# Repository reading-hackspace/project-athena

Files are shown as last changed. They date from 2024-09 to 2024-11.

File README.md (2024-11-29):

# Project Athena

A simple project to build and learn electronics and embedded design at rLab

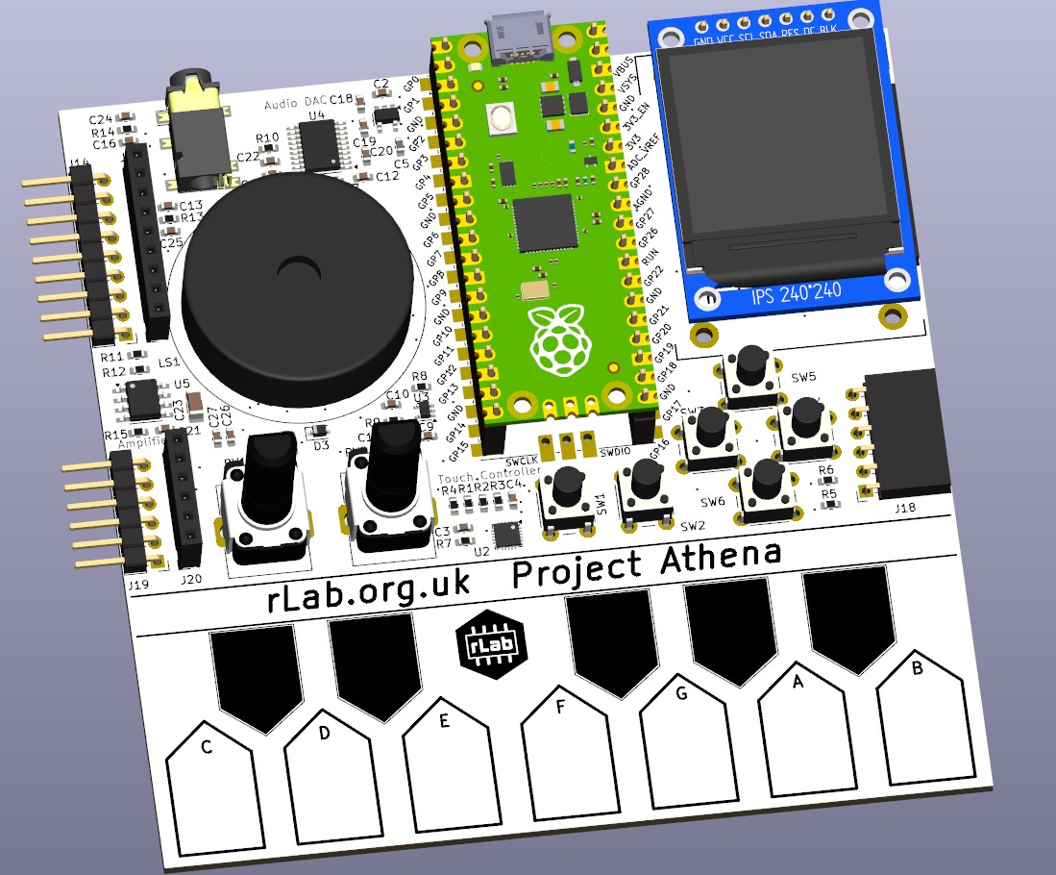
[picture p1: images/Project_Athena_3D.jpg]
Project Athena 3D


## Objectives:
<ul>
<li>Develop individual and shared electronic design skills</li>
<li>Learn PCB design and build techniques with Kicad and external PCB manufacturers</li>
<li>Improve surface mount and through hole soldering skills</li>
<li>Familiarise members with rLab electronics tools, equipment, and knowledge</li>
<li>Make a fun device</li>
</ul>

## Design Specification
Derived from the previous 555 Synth Punk construction project
<ul>
<li>design should be Microprocessor based rather than 555</li>
<li>It should have a keyboard. This could be buttons, stylophone, touch sensor, or other. Probably single octave.</li>
<li>Cost components and board under £10</li>
<li>Improved Audio output using proper amplifier IC and board mounted speaker, possibly I2S codec</li>
<li>A couple of knobs and buttons to change sound settings</li>
<li>USB powered</li>
<li>Audio output jack</li>
<li>Mixture of surface mount and through hole components</li>
<li>LCD display integral</li> 
<li>Expansion connector to add new personalised features</li>v
<li>C++ or Python programming.</li>
</ul>

## Design Approach
The design is built of modules which can be independently sourced, designed and prototyped before integration into a complete design.

## Proposed Modules
The following modules are proposed to be in the design, being available and at reasonable cost:

### Raspberry Pi Pico Processor Module
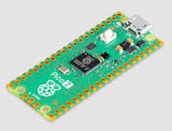
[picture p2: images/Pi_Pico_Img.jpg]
Pi Pico Image


The Raspberry Pi Pico module is based on the RP2040 microprocessor. The module includes flash memory, power supply, crystal clock and a USB interface. It is an easy way to to integrate this processor without detail PCB layout and at attractive cost.
The Pi Pico Module have different variants which are pin compatible. They offer different USB Connectors(Micro-B, USB-C), Wireless and bluetooth integrated, and a higher performance version in the RP2350.
[Pi Pico Data sheet](https://datasheets.raspberrypi.com/pico/pico-datasheet.pdf)

The RP2040 is an ARM Cortex M0+ 32 bit processor which operates at 133MHz and includes a wide range of integrated peripherals.
[RP2040 Data sheet](https://datasheets.raspberrypi.com/rp2040/rp2040-datasheet.pdf)

High quality software support for the RP2040 and Pi Pico Modules is available in C/C++ ([C SDK](https://www.raspberrypi.com/documentation/microcontrollers/c_sdk.html), and [Arduino Pi Pico](https://www.tomshardware.com/how-to/program-raspberry-pi-pico-with-arduino-ide)), and Python([Micropython](https://www.raspberrypi.com/documentation/microcontrollers/micropython.html), and [CircuitPython](https://circuitpython.org/board/raspberry_pi_pico/))

### Capacitive touch Music Keyboard
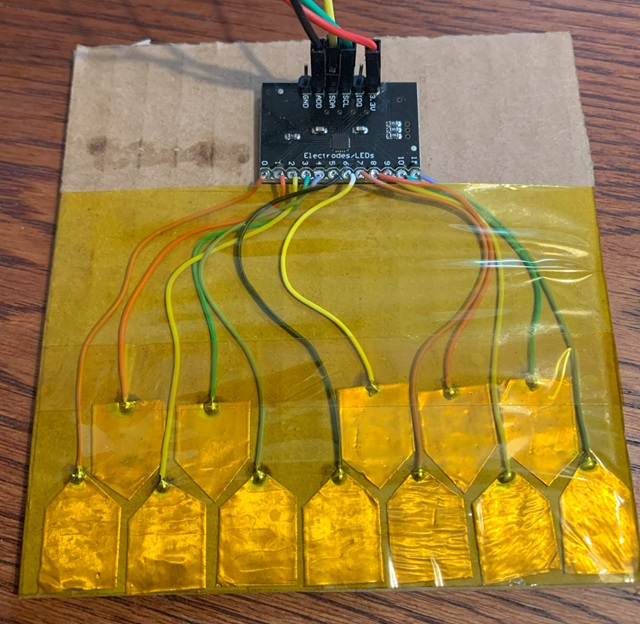
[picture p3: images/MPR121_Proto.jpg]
MPR121 Proto

A number of different keyboard switch types were considered including push butttons, stylophone type stylus and capacitive touch. The later was chosen for simplicity and the capability to play chords with multiple notes simultaneously.

A few different alternatives for the capacitive touch keyboard layout and interface were tested. The keyboard was prototyped with copper tape covered in kapton tape to simulate the PCB pads and solder mask in the final PCB. The Pi Pico does support direct connection of GPIO pins to interface capacitive touch switches using the CircuitPython [touchio library](https://docs.circuitpython.org/en/latest/shared-bindings/touchio/index.html), However it uses a lot of GPIO pins for a 12 key keyboard. It was decided to us a specialised Capacitive touch chip with and I2C interface [MPR121](https://www.nxp.com/docs/en/data-sheet/MPR121.pdf). This chip is very small and will present a good challenge in construction, however it is available already mounted on low cost modules for prototyping. The chip supports up to 4 different I2C addresses allowing additional octave to be added.

### PWM Audio Output
The Pi Pico supports PWM output to a GPIO pin for audio tone output. The resulting output is rather noisy as described in section 3.4.1 of the  [RP2040 hardware interface manual](https://datasheets.raspberrypi.com/rp2040/hardware-design-with-rp2040.pdf). It was chosen to implement the low noise 3.3V audio supply, the buffer, and the filter circuit.

### I2S Audio Codec
In addition to the PWM a I2S audio DAC is included for higher quality stereo output. The [PCM5102 DAC](https://www.ti.com/lit/ds/symlink/pcm5102.pdf) analog part is also powered from the low noise 3.3V supply

### Audio Amplifier and Loudspeaker
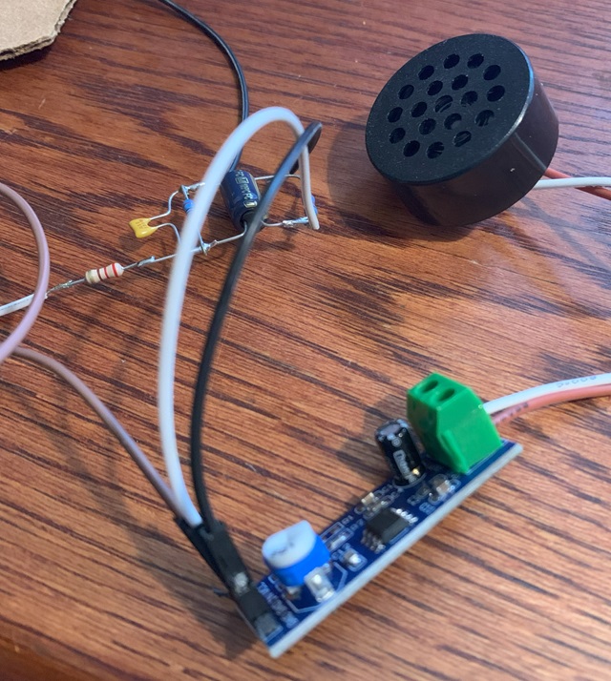
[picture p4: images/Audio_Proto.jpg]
Audio proto


Low cost audio power amplifiers with 1W output power baaed on the LM386 are available. [LM386 module](https://www.switchelectronics.co.uk/products/lm386-audio-amplifier-board-200-gain-amplifier-module-power)

The LM386 IC can operate with few external components with a gain of 20 which is suitable for our application.[LM386 Data sheet](https://www.ti.com/lit/ds/symlink/lm386.pdf)

The loudspeaker is proposed to be board mounted.[30mm Loudspeaker](https://proto-pic.co.uk/product/speaker-30mm-dia-8-ohm-pcb-mounted)

Audio Output to an external amplifier is provided via a 3.5mm stereo jack.

### 1.3 inch IPS Colour LCD Display
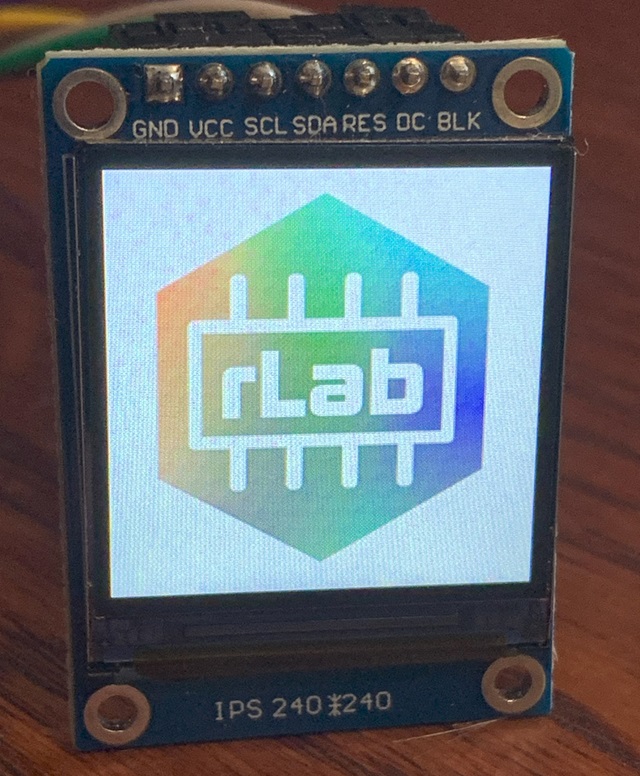
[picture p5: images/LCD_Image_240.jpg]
LCD Image


A colour LCD display was chosen for the device. Limited space allows for a [240 by 240 pixel 1.3 inch IPS display](https://www.smart-prototyping.com/1_3-inch-TFT-IPS-Display-Module-ST7789-SPI-240-240).
The module is based on the ST7789 display IC and is supported by both Micropython and CircuitPython grahics libraries.

### Buttons and Potentiometers.

To interact with the device and display, two potentiometers and six push buttons are included.

### General Purpose Inputs and Outputs.

The board provides spare GPIO connections and power supplies on 2.54mm female headers for external experimental devices. The I2c Bus is also brought out to a connectors to daisy chain octaves or add other I2C devices. The connectors can be male or female and mounted vertically or horizontally on the board

##   Estimated Costs
Derived from Kicad BOM. All including VAT and shipping.
<ul>
<li> PCB, 2 layer 100mm * 100mm JLCPCB      £0.75</li>
<li> Pi Pico 2040 module with micro USB     £1.75</li>
<li> 1.3in LCD Display 240 * 240 pixel      £1.75</li>
<li> Integrated circuits                    £1.25</li>
<li> Connectors                             £0.75</li>
<li> Buttons, Potentiometers                £0.50</li>

<li> Resistors, capacitors                  £0.75</li>
</ul>
Total: 

## PCB Files

## Software

The software is in early stage of test and development. The following capabilities have been tested:
<ul>
<li> Display colour rLab logo on LCD display in Circuit Python
<li> SImple one octave piano with output to internal speaker
<li> Polyphonic synthesiser with output via audio codec
<li> Nintendo style games (Tetris, Flappy Bird) with display and sound
<ul>

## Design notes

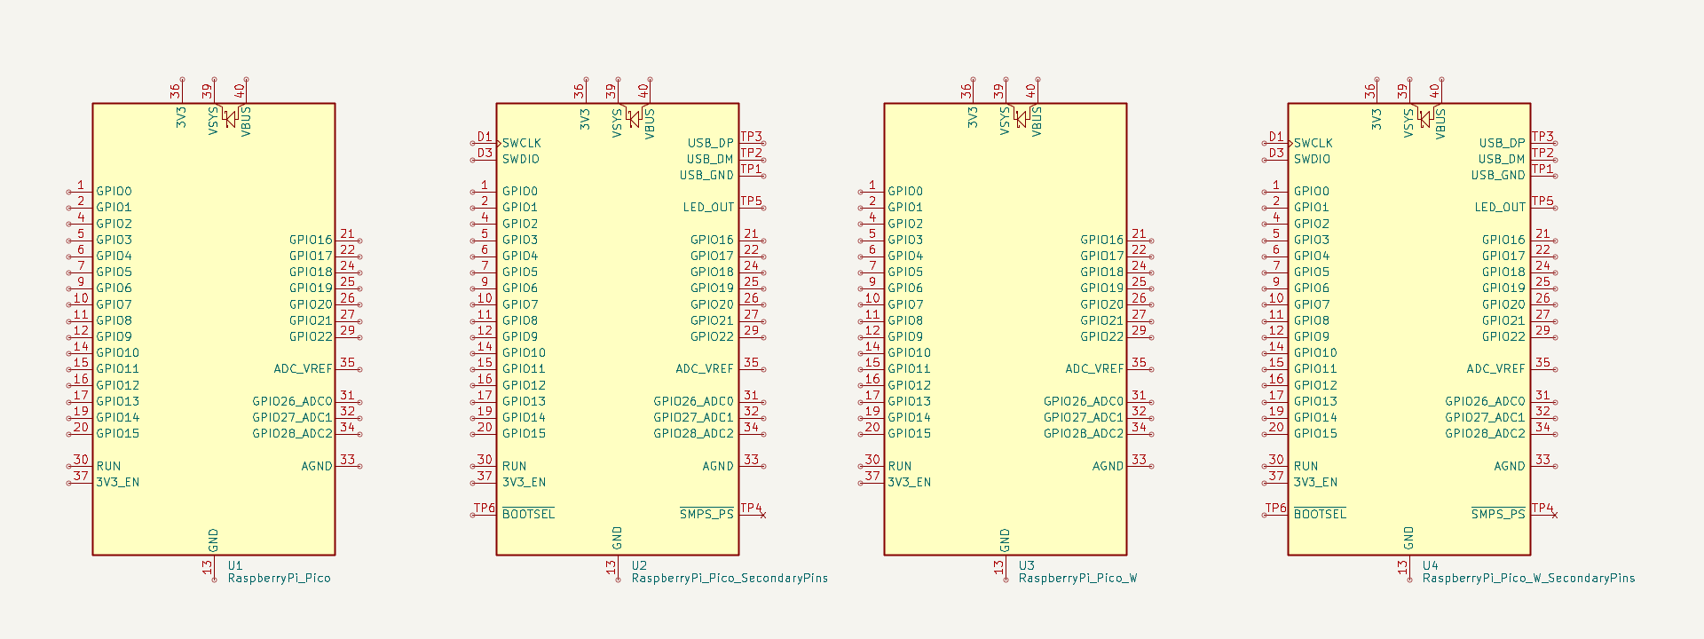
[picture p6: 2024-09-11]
Kicad/RLab Keyboard/ki-lime-pi-pico-2.1.2/_md-assets/images/schematics.png

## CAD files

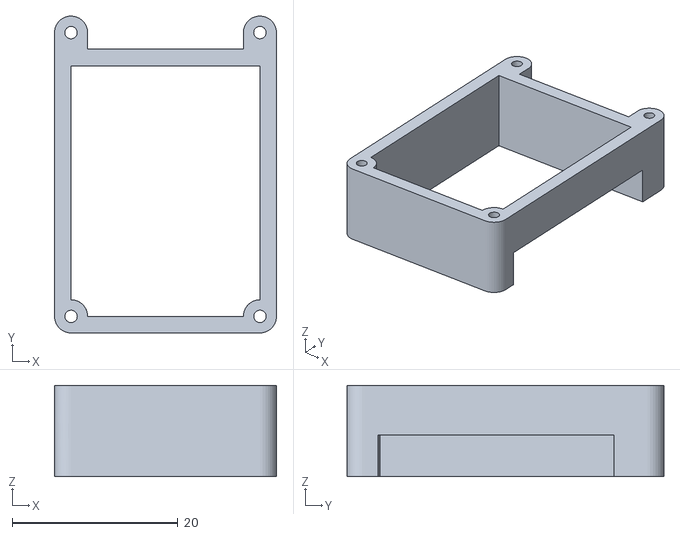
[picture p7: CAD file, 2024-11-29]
CAD/Display mount.stl
26.8 x 38.2 x 11.0

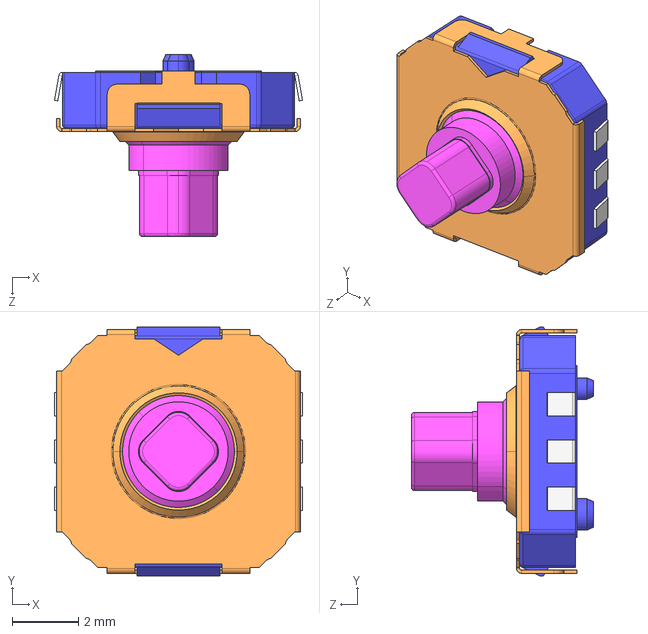
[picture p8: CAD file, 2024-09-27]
Kicad/RLab Keyboard/3D_Models/SKRHAB.STEP
7.48 x 7.50 x 5.50 mm

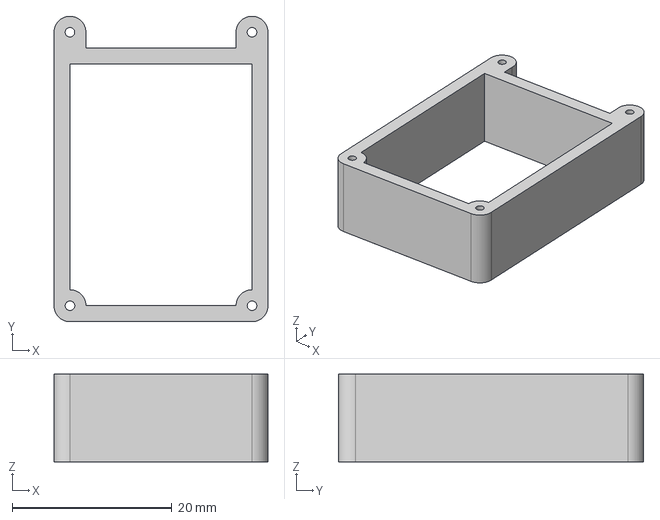
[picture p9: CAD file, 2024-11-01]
CAD/dispay_mount v3.step
26.8 x 38.2 x 11.0 mm

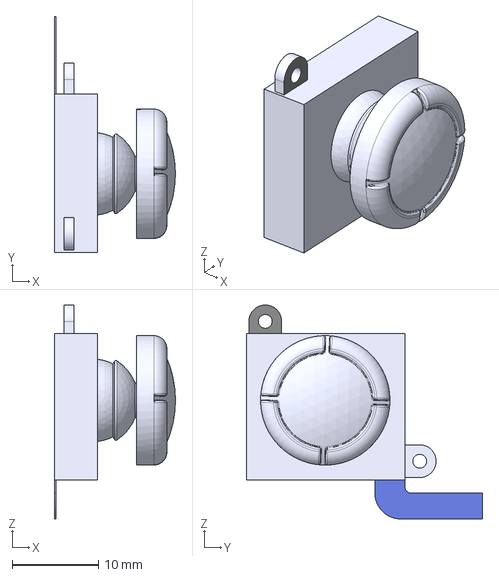
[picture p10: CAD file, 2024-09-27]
Kicad/RLab Keyboard/3D_Models/Switch JoyCon joystick v2.step
14.0 x 27.4 x 24.8 mm

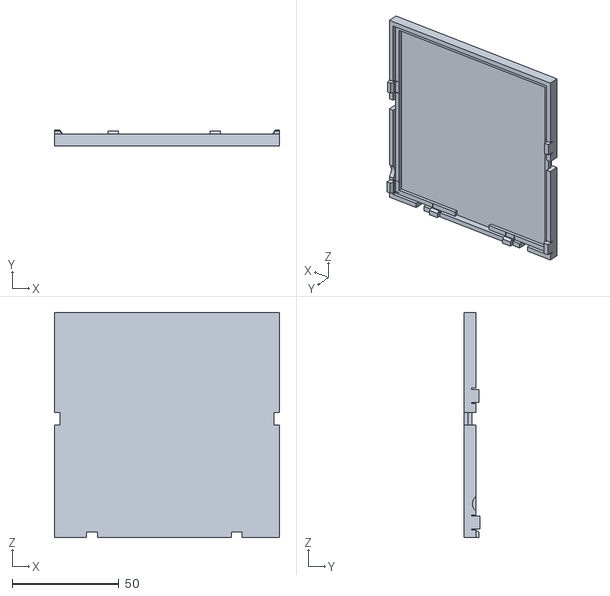
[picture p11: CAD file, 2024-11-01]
CAD/Athena_Base.stl
105.2 x 7.60 x 105.2

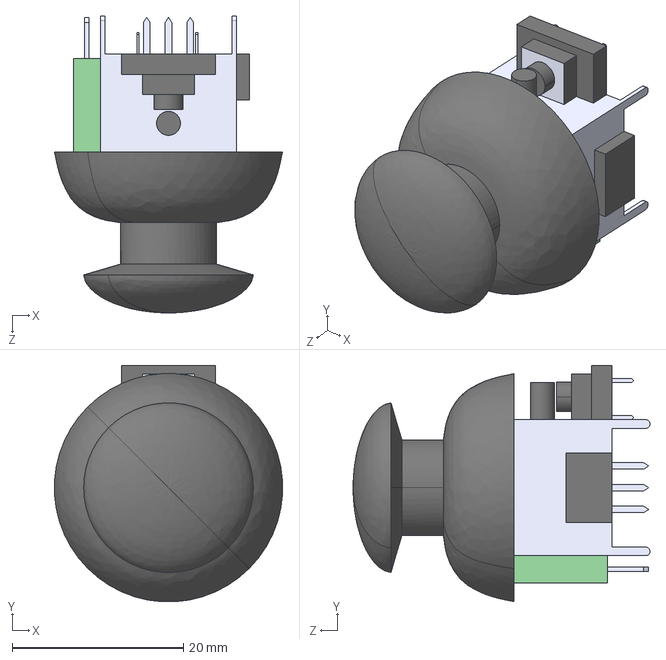
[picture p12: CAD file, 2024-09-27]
Kicad/RLab Keyboard/3D_Models/9032.STEP
26.6 x 27.6 x 34.7 mm

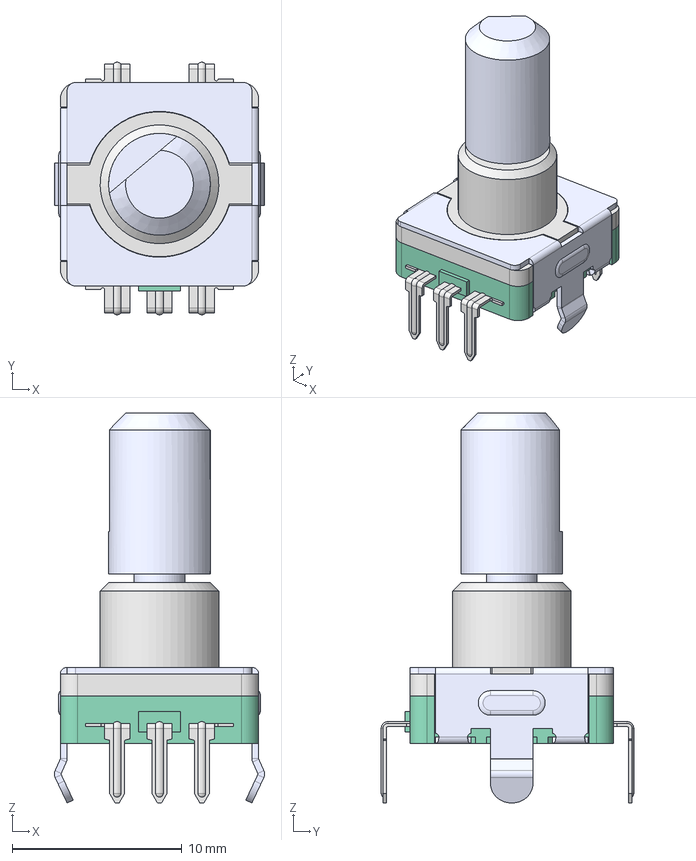
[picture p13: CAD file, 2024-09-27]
Kicad/RLab Keyboard/3D_Models/EC11-THT.step
12.4 x 14.9 x 23.0 mm
Lb5
15F
EC11-Housing-THT

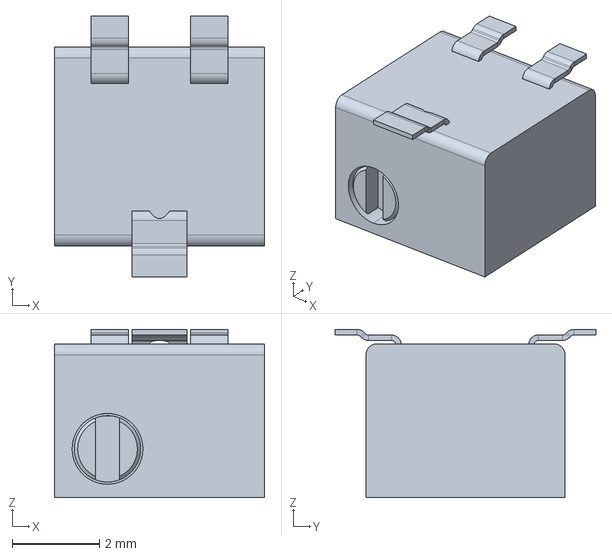
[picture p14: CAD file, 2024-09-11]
Kicad/RLab Keyboard/3D_Models/3214G.stp
4.83 x 5.99 x 3.86 mm

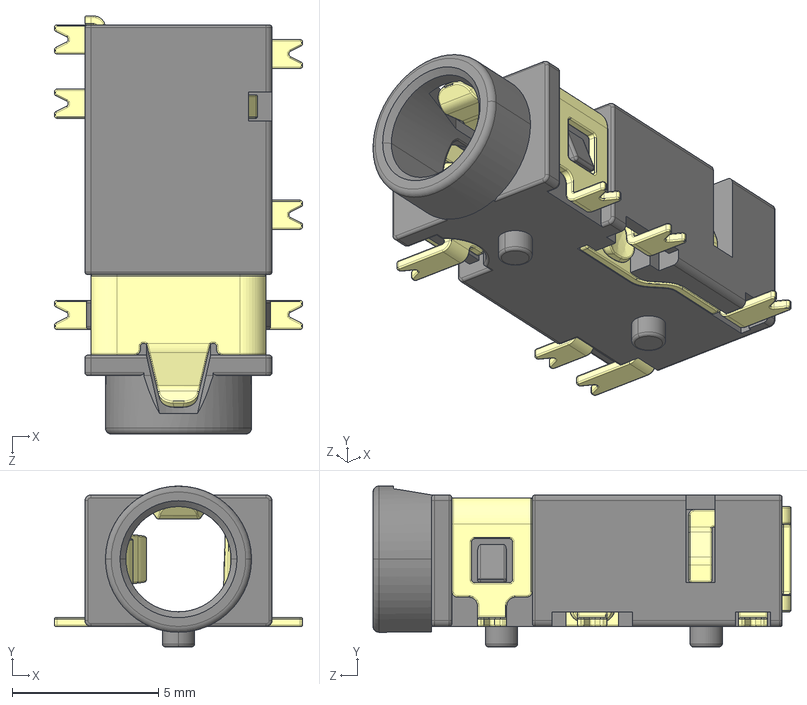
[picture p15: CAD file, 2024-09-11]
Kicad/RLab Keyboard/3D_Models/PJ311D_WPos.STEP
8.50 x 5.50 x 14.3 mm
001^PJ311D_WPos
002^PJ311D_WPos
003^PJ311D_WPos
004^PJ311D_WPos
005^PJ311D_WPos
006^PJ311D_WPos
007^PJ311D_WPos

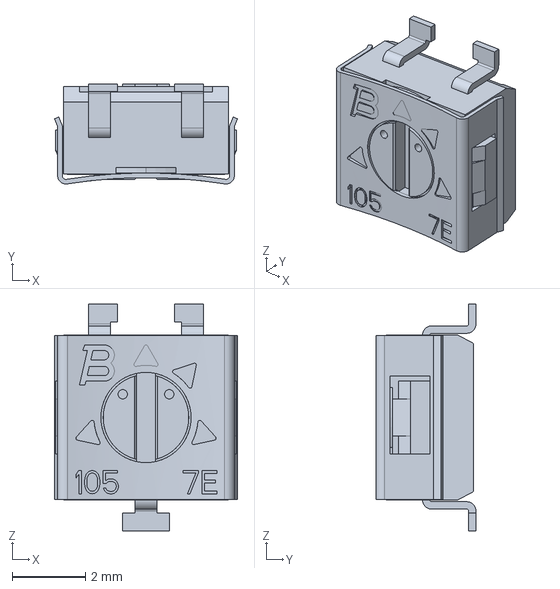
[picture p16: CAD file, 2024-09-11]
Kicad/RLab Keyboard/3D_Models/3314G1.stp
5.00 x 2.73 x 6.20 mm

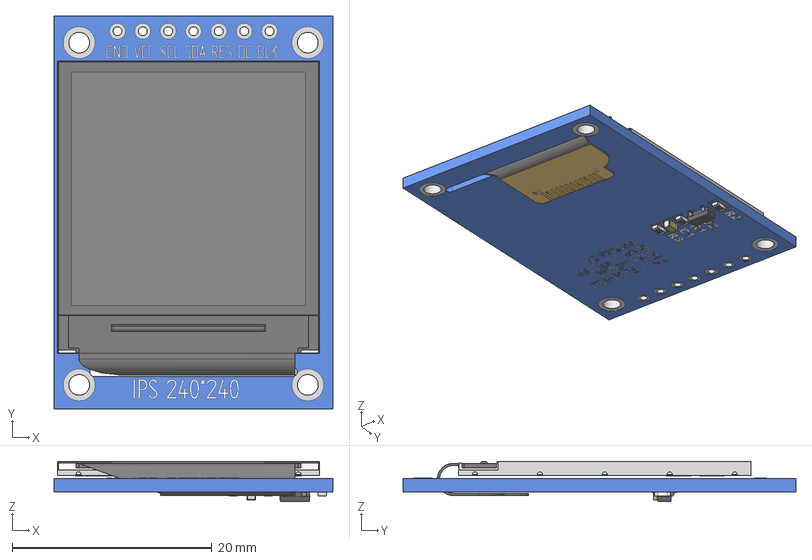
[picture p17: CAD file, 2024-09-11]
Kicad/RLab Keyboard/3D_Models/1.3 TFT IPS.stp
27.9 x 39.4 x 4.06 mm
1.3 TFT IPS - Board
1.3 TFT IPS - Flush Reverse Mount
0603 Resistor x 3
0603 Capacitor
SOT-23

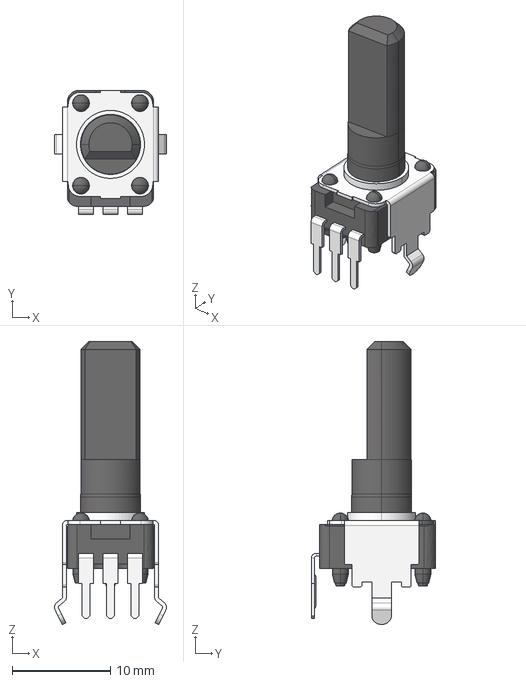
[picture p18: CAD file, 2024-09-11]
Kicad/RLab Keyboard/3D_Models/RK09K1130AH1.STEP
11.4 x 12.7 x 28.8 mm

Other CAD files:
Kicad/RLab Keyboard/KiCad-RP-Pico/SketchUp Model/Pico.skp
Kicad/RLab Keyboard/SW_SKRHABE010_SMD.blend

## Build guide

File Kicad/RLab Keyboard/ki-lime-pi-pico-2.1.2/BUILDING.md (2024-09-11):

**Instructions for building from source**
===========================================

> *Note that this project was largely leveraged for becoming more familiar with various aspects of KiCad, FreeCAD, and the Raspberry Pi Pico, and certain files may use exploratory workflows as a result.*

&nbsp;

# Development Environment

  Parametric models exported using [FreeCAD 0.21.2](https://github.com/FreeCAD/FreeCAD/releases/tag/0.21.2) with the [KiCad StepUp 12.2.6](https://github.com/easyw/kicadStepUpMod/tree/a7da10da12e405d106e1e9eb551444a289859ee8) workbench addon

  If you plan on committing changes to the .FCStd document and want (somewhat) trackable commits, then from the repository root call:

  ```bash
  mkdir -p .git/hooks
  cp .githooks/pre-commit.sh .git/hooks/pre-commit
  git config --local core.hooksPath .git/hooks
  ```

  *(If you are already using a `pre-commit` git hook, then manually add the content of `pre-commit.sh` to the existing hook instead)*

  > *Copying the file at a known state curbs the security concerns of remote changes to a hook.  Always audit scripts before using them.*

  Exported VRML models modified in [VSCodium 1.74.3](https://github.com/VSCodium/vscodium/releases/tag/1.74.3.23010)

  KiCad symbols and footprints exported using [KiCad 8.0.3](https://github.com/KiCad/kicad-source-mirror/releases/tag/8.0.3)

&nbsp;

# Symbols and Footprints

  KiCad symbols and footprints are already in the appropriate directories, so nothing needs to be done to prepare them for export.

&nbsp;

# Models

<details><summary>Regarding parametric colours</summary>
  
  > *Model faces are parametrically coloured via boolean operations between parts of varying diffuse colours.  To alter source colours for the board, see `Parametric_Source > Boards_Source > Parametric Board Colour Sources` in the `Tree view` panel and modify each Body's `Appearance`.  To alter source colours for components, be sure to modify the `Appearance` of the source Bodies **directly**, which are contained within the compounds/part containers in `Parametric_Source > Pico_Components_Source`.  Modifying the `Appearance` of the compounds/part containers or setting parts' face colours with `Set Colors...` will **not** parametrically populate.*
  >
  > *Note that as of FreeCAD 0.20.2 changing the sources of the colours does not automatically populate down all the dependent objects.  To get around this if you make any colour changes, when you are ready to export be sure to recompute the entire document as detailed below.  This should successfully populate the parametric colours across all dependent objects.*
  
</details>

  ### General

  - Open the models source file at `.../ki-lime-pi-pico/models/RaspberryPi_Pico_Variations.FCStd` in FreeCAD

    > Note: ~~If reproducible builds are important, be sure to stash any local changes to the file and reopen it before building so that you are recomputing from a known commit.~~  
    > ~~This is particularly important if you are using the `pre-commit` git hook described above.~~  
    > There is inconsistent noise generated with each recompute/export.  As a result, reproducible builds are not possible as built models will slightly differ each time.
  
  - If not already marked to recompute, in FreeCAD's `Tree view` panel `right-click` on the root document name `RaspberryPi_Pico_Variations` and select `Mark to recompute`

  - Click `Edit > Refresh` (or press `F5`) to recompute the entire document

  ### VRML

  - Enter the KiCad StepUp addon workbench from the drop-down menu at the top of the window

  - In FreeCAD's `Tree view` panel, locate the contents of the folder `Export > KiCad Model Outputs > VRML - Manually Coloured Clones`

  - If you are building from an official release commit, select the `Clone` you wish to export to a VRML file for KiCad (for example: `RaspberryPi_Pico`)  
    If you are building from a custom modification, you will likely need to recreate the `Draft Clones` from the parametrically coloured `Compounds` in `Export > KiCad Model Outputs > STEP - Parametrically Coloured Compounds`

    <details><summary>Additional information regarding clones and colours</summary>
      
      > *KiCad StepUp provides a selection of fully-featured materials that can be exported to VRML files.  Although the selection is limited, it provides convenient labelling of materials that can be edited later.  I have created `Clones` of each variation (which as of FreeCAD 0.20.2 do **not** parametrically preserve colour) and pre-set each face colour to align with colours defined within KiCad StepUp.*
      >
      > *Note that if you change geometry in any way which alters the number or topological location of faces anywhere within the model, these pre-set `Clones` will no longer be coloured appropriately*
      >
      > *You can always export from the parametrically coloured `Compounds` in `Export > KiCad Model Outputs > STEP - Parametrically Coloured Compounds`, just needing to set the export colours in KiCad StepUp each time as they will be reset upon recomputes.*
      
    </details>

  - Click on KiCad StepUp's `Export 3D Model` button (a graphic of a black 6-pin IC with a green arrow pointing down and to the right)

  - When prompted, I have used the values of `0.03 Mesh Deviation` and `0.5 creaseAngle` (old default values) and I find the results to be acceptable

  - If you are building from an official release commit, simply accept all the KiCad StepUp colour association prompts  
    If you are building from newly created `Clones`, you will need to manually set KiCad StepUp's colour associations.
    
    <details> <summary> Additional information regarding KiCad StepUp colour association </summary>
    
      > This part can be frustrating, as many parts appear off-white but are different materials.
      > When I built it, there are some colours which are automatically associated to a named material in KiCad StepUp; you shouldn't have to alter those.  
      > The remaining non-automatic colours broadly presented themselves in the following order:
      >
      > - `metal silver` (soldered pads)
      > - `pcb green`
      > - `light brown label` (FR4 core)
      > - `yellow body` (gold pins)
      > - `brown body` (caps)
      > - `resistor black body` (res/diode)
      > - `led white` (led lens)
      > - `light brown body` (led board)
      > - `green body` (led phosphor)
      > - `metal grey` (oscillator/wifi package)
      >
      > If this list doesn't appear to be accurate for you, then you can always set each colour to a high-contrasting material, and then select the appropriate material association in a second round of exporting.

    </details>

  - Repeat this for all `Clones`

  - Prepare a powerful text editor for bulk file editing

    <details> <summary> Specific instructions for preparing VSCodium/VSCode</summary>

      - Open a new VSCode-based instance

      - Select `File > Open Folder...`

      - Navigate to the directory `.../ki-lime-pi-pico/`

      - Select the folder `models/` and click `Select Folder`

      - Open each `.wrl` file by `double-clicking` each file in the `Explorer` pane

      - Select the magnifying glass on the left to open the `Search` pane

      - Expand the search box with the arrow to its left to reveal its find-and-replace functionality

      - Click the `...` in the bottom-right of the find-and-replace fields to expand additional options

      - Select the graphic of an open book in the `files to include` field to only process files which are currently open

    </details>

  - Find and replace the following material names in the newly created `.wrl` files:

    > *Be sure **not** to replace these material names in `MaterialsList.txt`!*

    | Original material   | Replace with
    |:-------------------:|:------------:
    | `PLASTIC-YELLOW-01` | `FINISH-GOLD`
    | `MET-SILVER`        | `FINISH-SILVER`
    | `RES-SMD-01`        | `IC-BODY-EPOXY-02`
    | `CAP-CERAMIC-06`    | `CAP-CERAMIC-01`
    | `MET-01`            | `FINISH-TIN`
    | `IC-LABEL-01`       | `BOARD-FR4-NATURAL`
    | `BOARD-GREEN-02`    | `MASK-PINE-GREEN`
    | `RES-THT-01`        | `MASK-LIGHT-TAN`
    | `LED-WHITE`         | `LED-LENS-CLEAR`
    | `PLASTIC-GREEN-01`  | `EMISSIVE-GREEN-PHOSPHOR`
  ##  
  - Finally, replace the default KiCad StepUp material definitions at the start of each `.wrl` file with the expanded list of materials found in `MaterialsList.txt`

    > *In VSCode-based editors, selecting `Match Case` in the search allows for the large blocks of material definition text to successfully be found and replaced*

    ---

  &nbsp;

  > *KiCad StepUp will automatically generate STEP files with limited hierarchy, part naming, and colour information as a result of the process above, so next we will export STEP models with more detailed information.*

  > *As of the time of writing, KiCad does not appropriately handle exporting part face colours when the component's STEP file uses assemblies.  To get around this, we will export our STEP models as `Compounds` for KiCad.  This will still result in limited hierarchy and part naming information, but will at least preserve face colours (excluding transparency) and discrete sub-components.*

  ### STEP (for KiCad)

  - In FreeCAD's `Tree view` panel, shift focus to the contents of the folder `Export > KiCad Model Outputs > STEP - Parametrically Coloured Compounds`

  - Manually select the root body you wish to export (for example: `RaspberryPi_Pico_Compound`)

  - Press `Ctrl + E`, or select `File > Export`

  - For ease, ensure the directory matches where KiCad StepUp exported its files to:
    `.../ki-lime-pi-pico/models/`

  - Ensure file type `"STEP with colors (*.step *.stp)"` is selected

  - Select the name of the already-generated model you intend to replace (for example: `RaspberryPi_Pico.step`)

  - Select `Save`, and select `Yes` when asked to replace the existing file

  - Repeat this for all models

  - Once all 3D models have been exported as `.wrl` and `.step` files, navigate to:

  ```
  .../ki-lime-pi-pico/models/
  ```

  - And **copy** (don't remove!) all `.wrl` and `.step` files to:

  ```
  .../ki-lime-pi-pico/kicad/project-libraries/RaspberryPi_Pico/Module_RaspberryPi_Pico.3dshapes/
  ```

  ---
  > *In addition to these KiCad models, we can also export a second set of STEP files to a supplemental directory, in the event any users have a need for the fully-featured assemblies.  Feel free to skip this section if all you need is a standalone KiCad library.*

  ### STEP (fully featured supplement)

  - In FreeCAD's `Tree view` panel, navigate into the folder `Export > STEP Assembly`

  - Manually select the root body you wish to export (for example: `RaspberryPi_Pico_STEP`)

  - Press `Ctrl + E`, or select `File > Export`

  - For ease, ensure again the directory matches where KiCad StepUp exported its files to:
    `.../ki-lime-pi-pico/models/`

  - Ensure file type `"STEP with colors (*.step *.stp)"` is selected

  - Select the name of the already-generated model you intend to replace again (for example: `RaspberryPi_Pico.step`)

  - Select `Save`, and select `Yes` when asked to replace the existing file

    > *As a result of using empty `Group` folders as a source of parametric part/feature naming, exporting these parts will result in an expected warning in the `Report view`.*

  - Repeat this for all models

  - Once these 3D models have been exported as `.step` files, navigate to:
  ```
  .../ki-lime-pi-pico/models/
  ```

  - And copy all `.step` files to:

  ```
  .../ki-lime-pi-pico/models/RaspberryPi_Pico_STEP/
  ```

  ### File cleanup

  - Navigate to `.../ki-lime-pi-pico/models/`

  - Delete the previously copied `.wrl` and `.step` files, as they are no longer needed in this directory

&nbsp;

# Final recommendations

As desired, navigate to our source's root directory:

```
.../ki-lime-pi-pico/
```

Append, replace, or otherwise modify files such as `LICENSE.txt`, `ATTRIBUTION.md`, and `README.md` to appropriately reflect your needs.

Copy the desired files *(for example, I include all three of `LICENSE.txt`, `ATTRIBUTION.md`, and `README.md` with the final build)* to:

```
.../ki-lime-pi-pico/kicad/project-libraries/RaspberryPi_Pico/
```

*I prefer to remove the references to images in the built library's `README.md` once it's copied here to keep it clean and compact.*

If you are also exporting the fully-featured supplemental STEP models, copy the desired files *(for example, I include `LICENSE.txt` and `ATTRIBUTION.md`)* to:

```
.../ki-lime-pi-pico/models/RaspberryPi_Pico_STEP/
```

&nbsp;

# **All done!** 🎉

Your completed library to reference, copy, and distribute as you wish can be found at:

```
.../ki-lime-pi-pico/kicad/project-libraries/RaspberryPi_Pico/
```

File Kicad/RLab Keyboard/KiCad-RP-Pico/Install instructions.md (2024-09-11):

# Install instructions

## 1. Copy the files locally

Copy the `RP-Pico Libraries` folder wherever you like on your computer.

## 2. Install the Raspberry Pi Pico board schema symbol

Use the `KiCad | Preferences | Manage Symbol Libraries...` command to manage the symbol library:



then select the global tab and click on the folder button:



navigate to the `RP-Pico Libraries` folder, select the `MCU_RaspberryPi_and_Boards.kicad_sym` file and open it:



et voilà, the first step is completed:



You can now close the symbol libraries manager window.

## 3. Install the Raspberry Pi Pico board footprint

You can use a similar approach to add the footprint to the footprint libraries manager, but I've found some issues that I've solved using the footprint editor, so here are the steps I suggest you to follow:

Open the footprint editor



wait for the footprints to load... then use the `File | Add Library` command:



confirm the `Global` choice:



and select the `MCU_RaspberriPi_and_Boards.pretty` folder (yes, the folder represent a footprint library on KiCad):



Now the library is installed on KiCad with the Raspberry Pi Pico footprint (double click on it to see it on the editor pane):



Don't close the windows as the next step start from here.

## 4. Install the Raspberry Pi Pico board footprint 3D visual

If not already open, open the the footprint editor

symbol library manager

double click on the `RPi_Pico_SMD_TH` footprint from the `MCU_RaspberriPi_and_Boards` library and then click on the `Footprint properties` icon:



In the footprint properties window, first select the `3D Settings` tab. Please note that the preview shows only the PCB board with the footprint added on step 3, without any 3D representation of the Raspberry Pi Pico board. Now click on the folder icon to add the 3D model:



Navigate to the `RP-Pico Libraries` folder, select the `Pico.wrl` file and wait until the model is shown in the right panel, then confirm with OK:



The model is already scaled and translated to match the footprint:



now close the `Footprint Properties` window, and the `Footprint Editor`, obviously saving the changes.

## Conclusion

Now that you've installed the schema and footprint and added the 3D model to the footprint, you can use the Raspberry Pi Pico board on your KiCad projects.

I've also added a test KiCad Project on the `Test` folder, that you can use to see an example of it.

Have fun!

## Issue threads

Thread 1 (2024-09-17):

New layout proposal

jeremypoulter, 2024-09-17:
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

This is a new layout proposal, key features:

- GPIO and I2C connections on both sides of the board to allow multiple boards to be daisy chained together
  - Simple I2C extended keyboard
  - Semi populated co-processo boards
- Audio/analogue side and Digital side
- Extra button so you can do a basic menu on the display (up/down/select)
  - Potentially we could also add the pins to swap the buttons for rotary encoders

jeremypoulter, 2024-11-05:
All done

Closed 2024-11-05.

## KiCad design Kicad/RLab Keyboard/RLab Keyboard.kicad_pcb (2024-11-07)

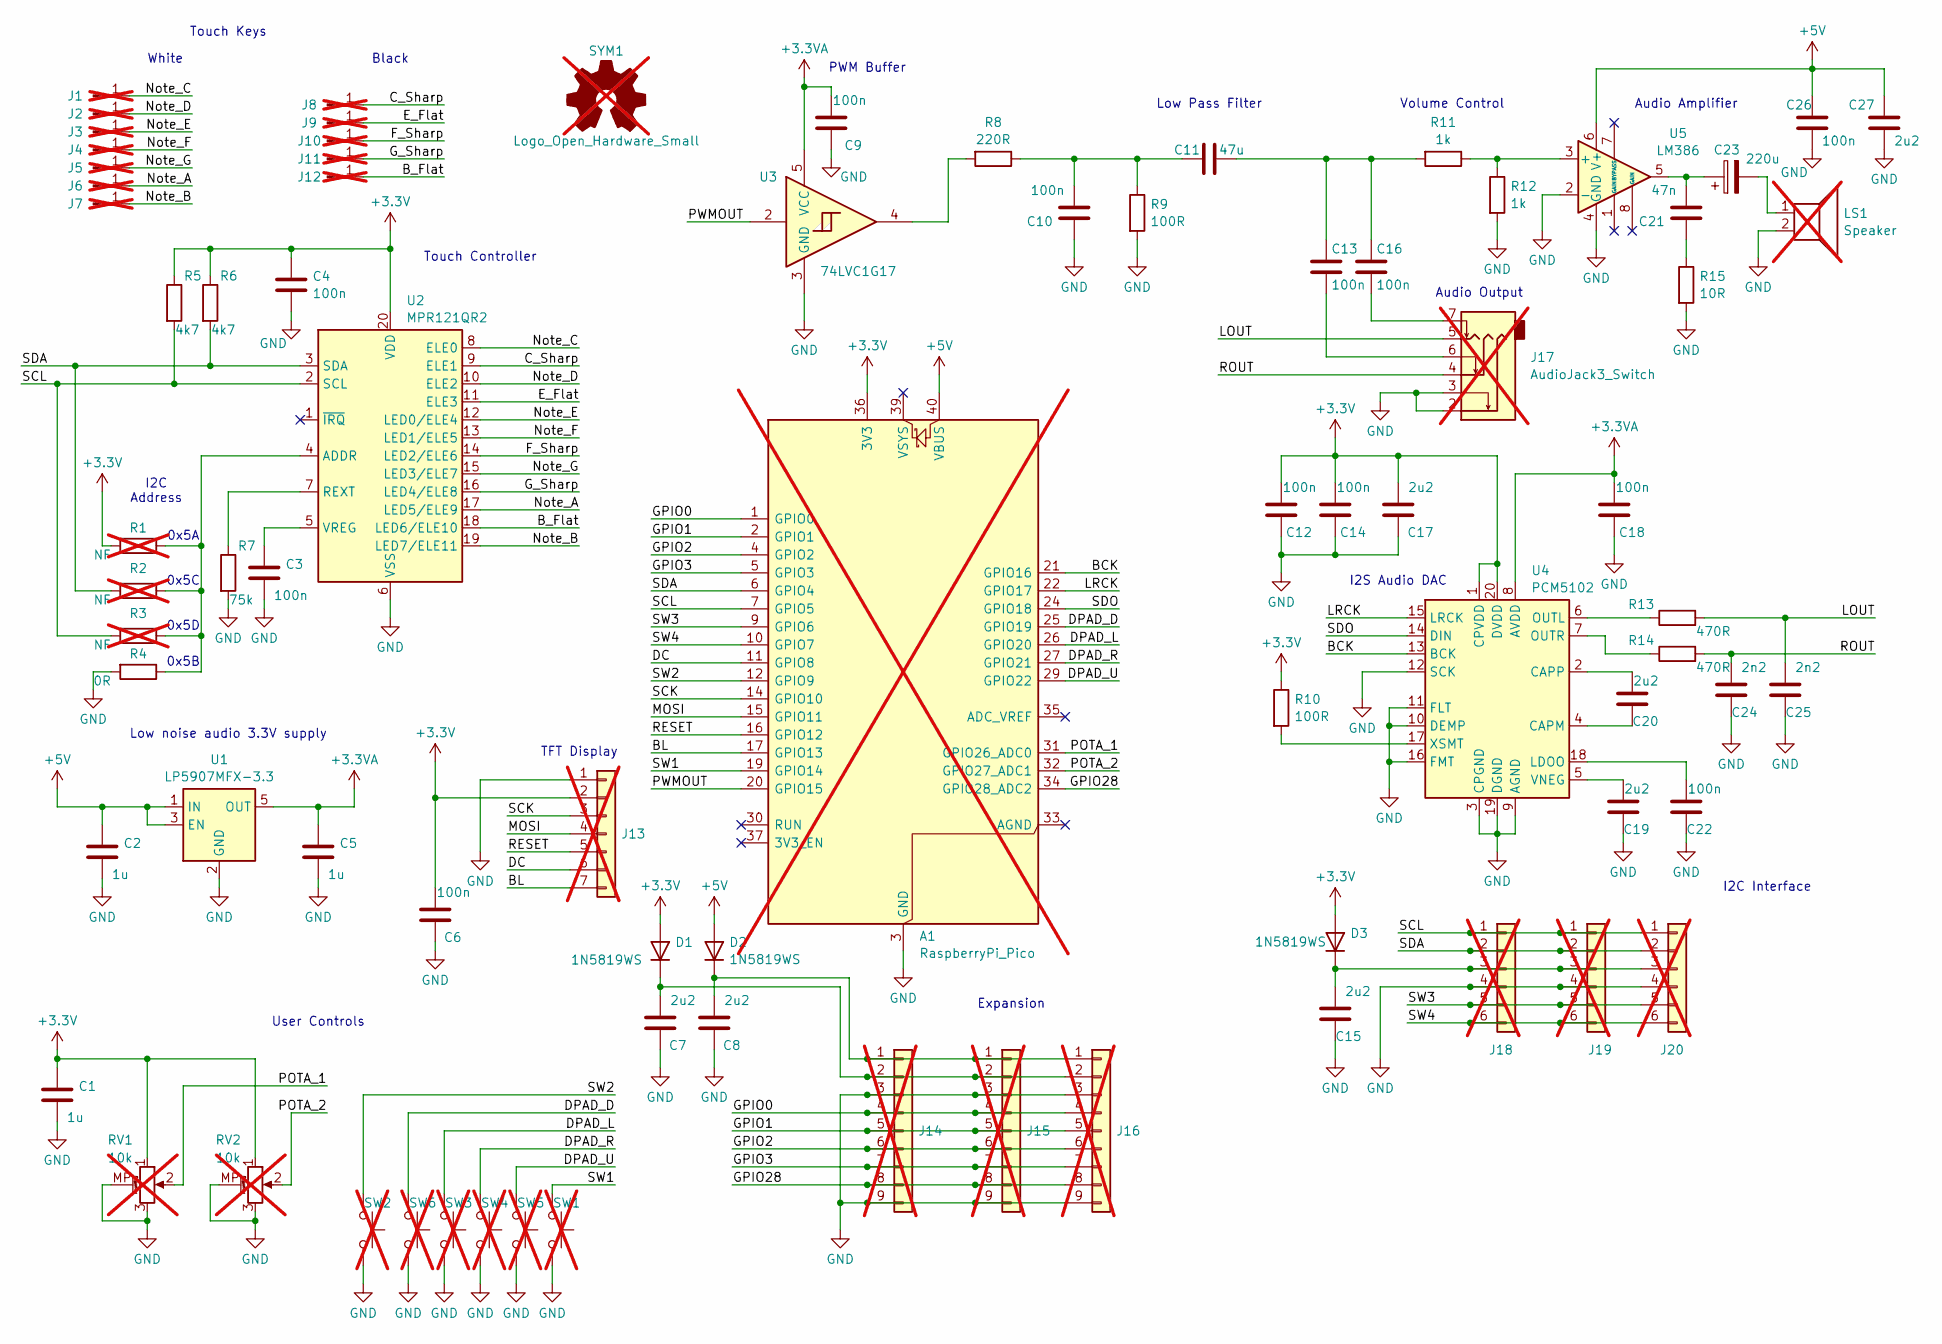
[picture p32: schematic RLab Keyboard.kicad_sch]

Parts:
A1: RaspberryPi_Pico; RPi_Pico_SMD_TH; not fitted
C1, C2, C5: 1u; C_0603_1608Metric; LCSC Part C111590
C3, C4, C6, C9, C10, C12, C13, C14, C16, C18, C22, C26: 100n; C_0603_1608Metric; LCSC Part C6119867
C7, C8, C15, C17, C19, C20, C27: 2u2; C_0603_1608Metric; LCSC Part C5189830
C11: 47u; C_0805_2012Metric; LCSC Part C19103846
C21: 47n; C_0603_1608Metric; LCSC Part C597218
C23: 220u; C_1206_3216Metric; LCSC Part C412252
C24, C25: 2n2; C_0603_1608Metric; LCSC Part C1604
D1, D2, D3: 1N5819WS; D_SOD-323; LCSC Part C191023
J1, J2, J3, J4, J5, J6, J7: Conn_01x01_Pin; White_Key; not fitted
J8, J9, J10, J11, J12: Conn_01x01_Pin; Black_key_fill; not fitted
J13: Conn_01x07; 240LCD; not fitted
J14: Conn_01x09; PinHeader_1x09_P2.54mm_Horizontal; not fitted
J15: Conn_01x09; PinSocket_1x09_P2.54mm_Vertical; not fitted
J16: Conn_01x09; PinSocket_1x09_P2.54mm_Horizontal; not fitted
J17: AudioJack3_Switch; Jack_3.5mm_PJ342_Horizontal; LCSC Part C668606; not fitted
J18: Conn_01x06; PinSocket_1x06_P2.54mm_Horizontal; not fitted
J19: Conn_01x06; PinHeader_1x06_P2.54mm_Horizontal; not fitted
J20: Conn_01x06; PinSocket_1x06_P2.54mm_Vertical; not fitted
LS1: Speaker; 30mm_Speaker; not fitted
R1, R2, R3: NF; R_0603_1608Metric; not fitted
R4: 0R; R_0603_1608Metric; LCSC Part C95177
R5, R6: 4k7; R_0603_1608Metric; LCSC Part C99782
R7: 75k; R_0603_1608Metric; LCSC Part C114636
R8: 220R; R_0603_1608Metric; LCSC Part C107696
R9, R10: 100R; R_0603_1608Metric; LCSC Part C105588
R11, R12: 1k; R_0603_1608Metric; LCSC Part C22548
R13, R14: 470R; R_0603_1608Metric; LCSC Part C114669
R15: 10R; R_0603_1608Metric; LCSC Part C22859
RV1, RV2: 10k; Potentiometer_Alps_RK09K_Single_Vertical; not fitted
SW1, SW2, SW3, SW4, SW5, SW6: SW_MEC_5G; SW_PUSH_6mm_H8mm; not fitted
SYM1: Logo_Open_Hardware_Small; OSHW-Logo_11.4x12mm_SilkScreen; not fitted
U1: LP5907MFX-3.3; SOT-23-5; LCSC Part C5370990
U2: MPR121QR2; UQFN-20_3x3mm_P0.4mm; LCSC Part C91322
U3: 74LVC1G17; SOT-353_SC-70-5; LCSC Part C19829654
U4: PCM5102; TSSOP-20_4.4x6.5mm_P0.65mm; LCSC Part C107671
U5: LM386; SOIC-8_3.9x4.9mm_P1.27mm; LCSC Part C22438596

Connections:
+3.3V: A1.36 (3V3), C1.1, C4.1, C6.2, C12.2, C14.2, C17.2, D1.2 (A), D3.2 (A), J13.2, R1.2, R5.1, R6.1, R10.1, RV1.1, RV2.1, U2.20 (VDD), U4.1 (CPVDD), U4.20 (DVDD)
+3.3VA: C5.1, C9.2, C18.2, U1.5 (OUT), U3.5 (VCC), U4.8 (AVDD)
+5V: A1.40 (VBUS), C2.1, C26.1, C27.2, D2.2 (A), U1.1 (IN), U1.3 (EN), U5.6 (V+)
/BCK: A1.21 (GPIO16), U4.13 (BCK)
/BL: A1.17 (GPIO13), J13.7
/B_Flat: J12.1, U2.18 (LED6/ELE10)
/C_Sharp: J8.1, U2.9 (ELE1)
/DC: A1.11 (GPIO8), J13.6
/DPAD_D: A1.25 (GPIO19), SW6.1
/DPAD_L: A1.26 (GPIO20), SW3.1
/DPAD_R: A1.27 (GPIO21), SW4.1
/DPAD_U: A1.29 (GPIO22), SW5.1
/E_Flat: J9.1, U2.11 (ELE3)
/F_Sharp: J10.1, U2.14 (LED2/ELE6)
/GPIO0: A1.1 (GPIO0), J14.4, J15.4, J16.4
/GPIO1: A1.2 (GPIO1), J14.5, J15.5, J16.5
/GPIO2: A1.4 (GPIO2), J14.6, J15.6, J16.6
/GPIO3: A1.5 (GPIO3), J14.7, J15.7, J16.7
/GPIO28: A1.34 (GPIO28_ADC2), J14.8, J15.8, J16.8
/G_Sharp: J11.1, U2.16 (LED4/ELE8)
/LOUT: C25.2, J17.5, R13.2
/LRCK: A1.22 (GPIO17), U4.15 (LRCK)
/MOSI: A1.15 (GPIO11), J13.4
/Note_A: J6.1, U2.17 (LED5/ELE9)
/Note_B: J7.1, U2.19 (LED7/ELE11)
/Note_C: J1.1, U2.8 (ELE0)
/Note_D: J2.1, U2.10 (ELE2)
/Note_E: J3.1, U2.12 (LED0/ELE4)
/Note_F: J4.1, U2.13 (LED1/ELE5)
/Note_G: J5.1, U2.15 (LED3/ELE7)
/POTA_1: A1.31 (GPIO26_ADC0), RV1.2
/POTA_2: A1.32 (GPIO27_ADC1), RV2.2
/PWMOUT: A1.20 (GPIO15), U3.2
/RESET: A1.16 (GPIO12), J13.5
/ROUT: C24.2, J17.4, R14.2
/SCK: A1.14 (GPIO10), J13.3
/SCL: A1.7 (GPIO5), J18.1, J19.1, J20.1, R3.2, R5.2, U2.2 (SCL)
/SDA: A1.6 (GPIO4), J18.2, J19.2, J20.2, R2.2, R6.2, U2.3 (SDA)
/SDO: A1.24 (GPIO18), U4.14 (DIN)
/SW1: A1.19 (GPIO14), SW1.1
/SW2: A1.12 (GPIO9), SW2.1
/SW3: A1.9 (GPIO6), J18.5, J19.5, J20.5
/SW4: A1.10 (GPIO7), J18.6, J19.6, J20.6
GND: A1.3 (GND), A1.8 (GND), A1.13 (GND), A1.18 (GND), A1.23 (GND), A1.28 (GND), A1.38 (GND), C1.2, C2.2, C3.2, C4.2, C5.2, C6.1, C7.1, C8.1, C9.1, C10.1, C12.1, C14.1, C15.1, C17.1, C18.1, C19.1, C22.1, C24.1, C25.1, C26.2, C27.1, J13.1, J14.3, J14.9, J15.3, J15.9, J16.3, J16.9, J17.2, J17.3, J18.4, J19.4, J20.4, LS1.2, R4.2, R7.2, R9.2, R12.2, R15.2, RV1.3, RV1.MP (MountPin), RV2.3, RV2.MP (MountPin), SW1.2, SW2.2, SW3.2, SW4.2, SW5.2, SW6.2, U1.2 (GND), U2.6 (VSS), U3.3 (GND), U4.3 (CPGND), U4.9 (AGND), U4.10 (DEMP), U4.11 (FLT), U4.12 (SCK), U4.16 (FMT), U4.19 (DGND), U5.2 (-), U5.4 (GND)
unnamed: C10.2, C11.2, R8.1, R9.1
unnamed: C11.1, C13.1, C16.1, R11.2
unnamed: C13.2, J17.6
unnamed: C16.2, J17.7
unnamed: C21.1, R15.1
unnamed: C21.2, C23.1, U5.5
unnamed: C23.2, LS1.1
unnamed: C7.2, D1.1 (K), J14.2, J15.2, J16.2
unnamed: C8.2, D2.1 (K), J14.1, J15.1, J16.1
unnamed: C15.2, D3.1 (K), J18.3, J19.3, J20.3
unnamed: R8.2, U3.4
unnamed: R1.1, R2.1, R3.1, R4.1, U2.4 (ADDR)
unnamed: R7.1, U2.7 (REXT)
unnamed: C3.1, U2.5 (VREG)
unnamed: C20.1, U4.4 (CAPM)
unnamed: C20.2, U4.2 (CAPP)
unnamed: C22.2, U4.18 (LDOO)
unnamed: R13.1, U4.6 (OUTL)
unnamed: R14.1, U4.7 (OUTR)
unnamed: C19.2, U4.5 (VNEG)
unnamed: R10.2, U4.17 (XSMT)
unnamed: R11.1, R12.1, U5.3 (+)

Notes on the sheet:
PWM Buffer
Black
I2C Address
Touch Keys
Audio Amplifier
0x5C
0x5A
Audio Output
0x5B
TFT Display
Low noise audio 3.3V supply
Volume Control
Low Pass Filter
I2C Interface
Expansion
0x5D
I2S Audio DAC
User Controls
Touch Controller
White

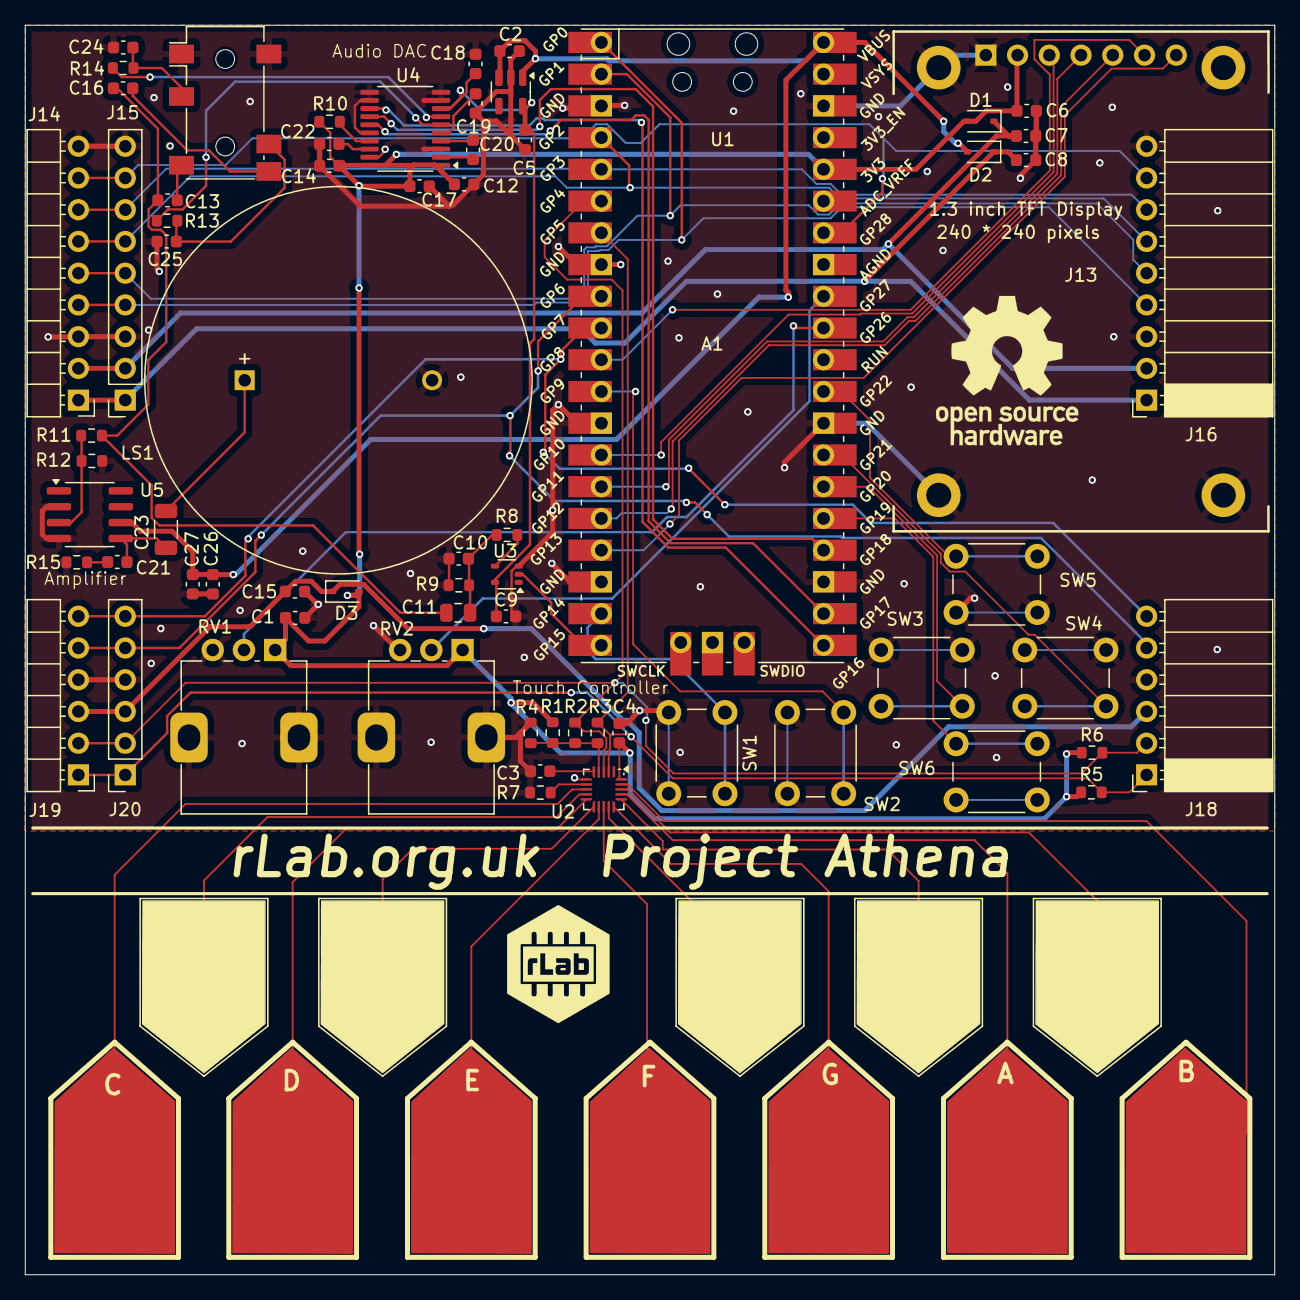
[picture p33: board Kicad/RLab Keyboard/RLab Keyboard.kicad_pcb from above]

Board: 2 copper layers, 100.0 x 100.0 mm, 81 parts (0 on the bottom side), 66 nets.

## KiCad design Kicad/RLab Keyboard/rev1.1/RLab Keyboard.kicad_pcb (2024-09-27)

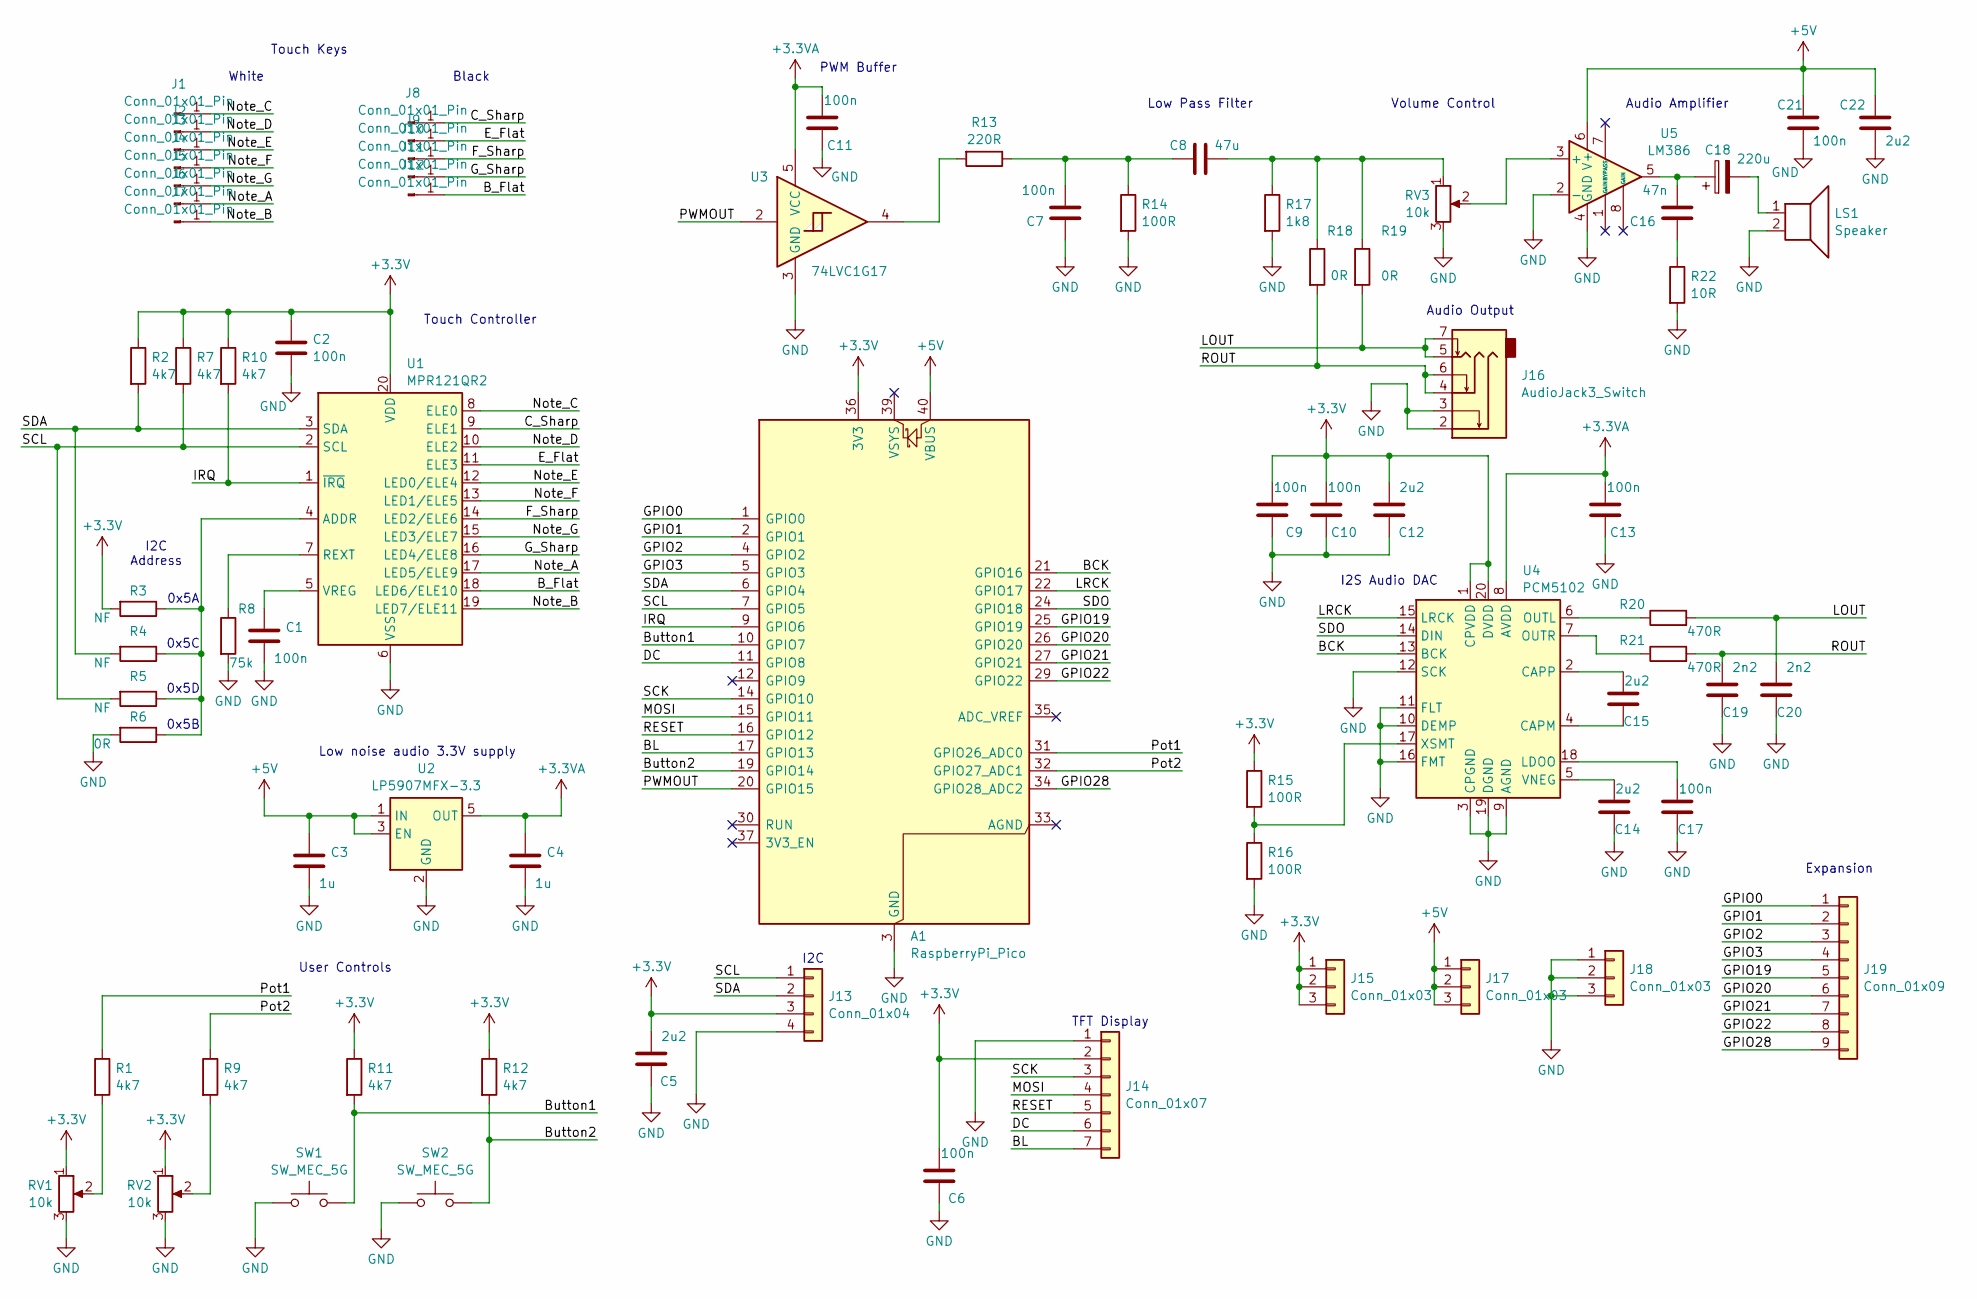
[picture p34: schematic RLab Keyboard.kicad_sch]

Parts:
A1: RaspberryPi_Pico; RPi_Pico_SMD_TH
C1, C2, C6, C7, C9, C10, C11, C13, C17, C21: 100n; C_0603_1608Metric
C3, C4: 1u; C_0603_1608Metric
C5, C12, C14, C15, C22: 2u2; C_0603_1608Metric
C8: 47u; C_0805_2012Metric
C16: 47n; C_0603_1608Metric
C18: 220u; C_1206_3216Metric
C19, C20: 2n2; C_0603_1608Metric
J1, J2, J3, J4, J5, J6, J7: Conn_01x01_Pin; White_Key
J8, J9, J10, J11, J12: Conn_01x01_Pin; Black_key_fill
J13: Conn_01x04; PinSocket_1x04_P2.54mm_Vertical
J14: Conn_01x07; 240LCD
J15, J17, J18: Conn_01x03; PinSocket_1x03_P2.54mm_Vertical
J16: AudioJack3_Switch; Jack_3.5mm_PJ342_Horizontal
J19: Conn_01x09; PinSocket_1x09_P2.54mm_Vertical
LS1: Speaker; 30mm_Speaker
R1, R2, R7, R9, R10, R11, R12: 4k7; R_0603_1608Metric
R3, R4, R5: NF; R_0603_1608Metric
R6, R18, R19: 0R; R_0603_1608Metric
R8: 75k; R_0603_1608Metric
R13: 220R; R_0603_1608Metric
R14, R15, R16: 100R; R_0603_1608Metric
R17: 1k8; R_0603_1608Metric
R20, R21: 470R; R_0603_1608Metric
R22: 10R; R_0603_1608Metric
RV1, RV2: 10k; Potentiometer_Alps_RK09K_Single_Vertical
RV3: 10k; Potentiometer_Bourns_3214G_Horizontal
SW1, SW2: SW_MEC_5G; SW_PUSH_6mm_H5mm
U1: MPR121QR2; UQFN-20_3x3mm_P0.4mm
U2: LP5907MFX-3.3; SOT-23-5
U3: 74LVC1G17; SOT-353_SC-70-5
U4: PCM5102; TSSOP-20_4.4x6.5mm_P0.65mm
U5: LM386; SOIC-8_3.9x4.9mm_P1.27mm

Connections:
+3.3V: A1.36 (3V3), C2.1, C5.2, C6.2, C9.2, C10.2, C12.2, J13.3, J14.2, J15.1, J15.2, J15.3, R2.1, R3.2, R7.1, R10.1, R11.1, R12.1, R15.1, RV1.1, RV2.1, U1.20 (VDD), U4.1 (CPVDD), U4.20 (DVDD)
+3.3VA: C4.1, C11.2, C13.2, U2.5 (OUT), U3.5 (VCC), U4.8 (AVDD)
+5V: A1.40 (VBUS), C3.1, C21.1, C22.2, J17.1, J17.2, J17.3, U2.1 (IN), U2.3 (EN), U5.6 (V+)
/BCK: A1.21 (GPIO16), U4.13 (BCK)
/BL: A1.17 (GPIO13), J14.7
/B_Flat: J12.1, U1.18 (LED6/ELE10)
/Button1: A1.10 (GPIO7), R11.2, SW1.2
/Button2: A1.19 (GPIO14), R12.2, SW2.2
/C_Sharp: J8.1, U1.9 (ELE1)
/DC: A1.11 (GPIO8), J14.6
/E_Flat: J9.1, U1.11 (ELE3)
/F_Sharp: J10.1, U1.14 (LED2/ELE6)
/GPIO0: A1.1 (GPIO0), J19.1
/GPIO1: A1.2 (GPIO1), J19.2
/GPIO2: A1.4 (GPIO2), J19.3
/GPIO3: A1.5 (GPIO3), J19.4
/GPIO19: A1.25 (GPIO19), J19.5
/GPIO20: A1.26 (GPIO20), J19.6
/GPIO21: A1.27 (GPIO21), J19.7
/GPIO22: A1.29 (GPIO22), J19.8
/GPIO28: A1.34 (GPIO28_ADC2), J19.9
/G_Sharp: J11.1, U1.16 (LED4/ELE8)
/IRQ: A1.9 (GPIO6), R10.2, U1.1 (~IRQ)
/LOUT: C20.2, J16.5, J16.7, R19.2, R20.2
/LRCK: A1.22 (GPIO17), U4.15 (LRCK)
/MOSI: A1.15 (GPIO11), J14.4
/Note_A: J6.1, U1.17 (LED5/ELE9)
/Note_B: J7.1, U1.19 (LED7/ELE11)
/Note_C: J1.1, U1.8 (ELE0)
/Note_D: J2.1, U1.10 (ELE2)
/Note_E: J3.1, U1.12 (LED0/ELE4)
/Note_F: J4.1, U1.13 (LED1/ELE5)
/Note_G: J5.1, U1.15 (LED3/ELE7)
/PWMOUT: A1.20 (GPIO15), U3.2
/Pot1: A1.31 (GPIO26_ADC0), R1.1
/Pot2: A1.32 (GPIO27_ADC1), R9.1
/RESET: A1.16 (GPIO12), J14.5
/ROUT: C19.2, J16.4, J16.6, R18.2, R21.2
/SCK: A1.14 (GPIO10), J14.3
/SCL: A1.7 (GPIO5), J13.1, R5.2, R7.2, U1.2 (SCL)
/SDA: A1.6 (GPIO4), J13.2, R2.2, R4.2, U1.3 (SDA)
/SDO: A1.24 (GPIO18), U4.14 (DIN)
GND: A1.3 (GND), A1.8 (GND), A1.13 (GND), A1.18 (GND), A1.23 (GND), A1.28 (GND), A1.38 (GND), C1.2, C2.2, C3.2, C4.2, C5.1, C6.1, C7.1, C9.1, C10.1, C11.1, C12.1, C13.1, C14.1, C17.1, C19.1, C20.1, C21.2, C22.1, J13.4, J14.1, J16.2, J16.3, J18.1, J18.2, J18.3, LS1.2, R6.2, R8.2, R14.2, R16.2, R17.2, R22.2, RV1.3, RV2.3, RV3.3, SW1.1, SW2.1, U1.6 (VSS), U2.2 (GND), U3.3 (GND), U4.3 (CPGND), U4.9 (AGND), U4.10 (DEMP), U4.11 (FLT), U4.12 (SCK), U4.16 (FMT), U4.19 (DGND), U5.2 (-), U5.4 (GND)
unnamed: C7.2, C8.2, R13.1, R14.1
unnamed: C8.1, R17.1, R18.1, R19.1, RV3.1
unnamed: C16.1, R22.1
unnamed: C16.2, C18.1, U5.5
unnamed: C18.2, LS1.1
unnamed: R1.2, RV1.2
unnamed: R9.2, RV2.2
unnamed: R13.2, U3.4
unnamed: R3.1, R4.1, R5.1, R6.1, U1.4 (ADDR)
unnamed: R8.1, U1.7 (REXT)
unnamed: C1.1, U1.5 (VREG)
unnamed: C15.1, U4.4 (CAPM)
unnamed: C15.2, U4.2 (CAPP)
unnamed: C17.2, U4.18 (LDOO)
unnamed: R20.1, U4.6 (OUTL)
unnamed: R21.1, U4.7 (OUTR)
unnamed: C14.2, U4.5 (VNEG)
unnamed: R15.2, R16.1, U4.17 (XSMT)
unnamed: RV3.2, U5.3 (+)

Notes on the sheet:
PWM Buffer
Black
I2C Address
Touch Keys
Audio Amplifier
0x5C
0x5A
Audio Output
0x5B
TFT Display
Low noise audio 3.3V supply
Volume Control
Low Pass Filter
I2C
Expansion
0x5D
I2S Audio DAC
User Controls
Touch Controller
White

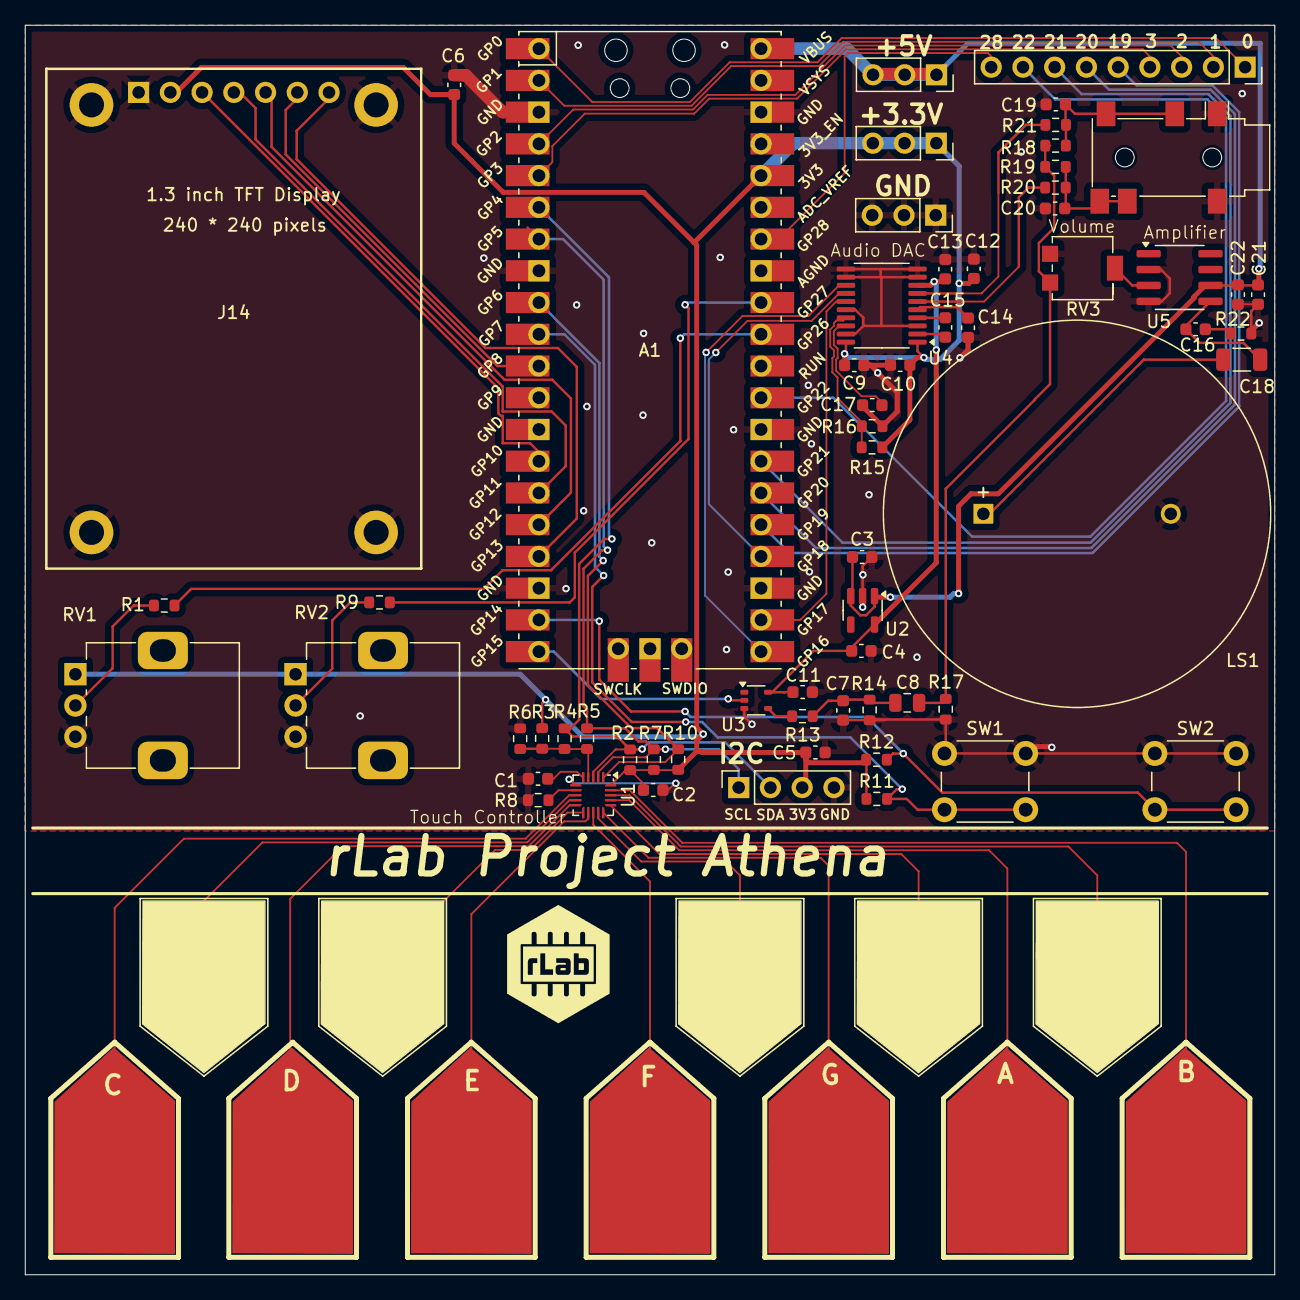
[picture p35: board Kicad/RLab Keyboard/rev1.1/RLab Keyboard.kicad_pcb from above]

Board: 2 copper layers, 100.0 x 100.0 mm, 75 parts (0 on the bottom side), 62 nets.

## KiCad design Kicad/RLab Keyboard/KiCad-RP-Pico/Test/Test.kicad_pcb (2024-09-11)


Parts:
J1, J2: Conn_01x20; PinSocket_1x20_P1.00mm_Vertical
J3: Conn_01x03; PinSocket_1x03_P1.00mm_Vertical
U1: Pico; RPi_Pico_SMD_TH

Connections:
GND: J1.3, J1.8, J1.13, J1.18, J2.3, J2.13, J2.18, J3.2, U1.3 (GND), U1.8 (GND), U1.13 (GND), U1.18 (GND), U1.23 (GND), U1.28 (GND), U1.38 (GND), U1.42 (GND)
unnamed: J1.1, U1.1 (GPIO0)
unnamed: J1.2, U1.2 (GPIO1)
unnamed: J1.4, U1.4 (GPIO2)
unnamed: J1.5, U1.5 (GPIO3)
unnamed: J1.6, U1.6 (GPIO4)
unnamed: J1.7, U1.7 (GPIO5)
unnamed: J1.9, U1.9 (GPIO6)
unnamed: J1.10, U1.10 (GPIO7)
unnamed: J1.11, U1.11 (GPIO8)
unnamed: J1.12, U1.12 (GPIO9)
unnamed: J1.14, U1.14 (GPIO10)
unnamed: J1.15, U1.15 (GPIO11)
unnamed: J1.16, U1.16 (GPIO12)
unnamed: J1.17, U1.17 (GPIO13)
unnamed: J1.19, U1.19 (GPIO14)
unnamed: J1.20, U1.20 (GPIO15)
unnamed: J2.1, U1.40 (VBUS)
unnamed: J2.2, U1.39 (VSYS)
unnamed: J2.4, U1.37 (3V3_EN)
unnamed: J2.5, U1.36 (3V3)
unnamed: J2.6, U1.35 (ADC_VREF)
unnamed: J2.7, U1.34 (GPIO28_ADC2)
unnamed: J2.8, U1.33 (AGND)
unnamed: J2.9, U1.32 (GPIO27_ADC1)
unnamed: J2.10, U1.31 (GPIO26_ADC0)
unnamed: J2.11, U1.30 (RUN)
unnamed: J2.12, U1.29 (GPIO22)
unnamed: J2.14, U1.27 (GPIO21)
unnamed: J2.15, U1.26 (GPIO20)
unnamed: J2.16, U1.25 (GPIO19)
unnamed: J2.17, U1.24 (GPIO18)
unnamed: J2.19, U1.22 (GPIO17)
unnamed: J2.20, U1.21 (GPIO16)
unnamed: J3.1, U1.43 (SWDIO)
unnamed: J3.3, U1.41 (SWCLK)


Board: 2 copper layers, 43.0 x 65.0 mm, 4 parts (0 on the bottom side), 36 nets.

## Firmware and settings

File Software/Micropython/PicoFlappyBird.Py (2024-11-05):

# PicoFlappyBird.py by Matthieu Mistler
# Flappy Bird game for the Raspberry Pi Pico Game Boy

from PicoGameBoy import PicoGameBoy
import time
from random import randint

pgb = PicoGameBoy()

#Picture importation

sprite1_34x24=bytearray(b'v9v9v9v9v9v9v9v9v9v9v9v9Q\xc8Q\xc8Q\xc8Q\xc8Q\xc8Q\xc8Q\xc8Q\xc8Q\xc8Q\xc8Q\xc8Q\xc8v9v9v9v9v9v9v9v9v9v9v9v9v9v9v9v9v9v9v9v9v9v9Q\xc8Q\xc8Q\xc8Q\xc8Q\xc8Q\xc8Q\xc8Q\xc8Q\xc8Q\xc8Q\xc8Q\xc8v9v9v9v9v9v9v9v9v9v9v9v9v9v9v9v9v9v9Q\xc8Q\xc8Q\xc8Q\xc8\xdf\x16\xdf\x16\xdf\x16\xdf\x16\xdf\x16\xdf\x16Q\xc8Q\xc8\xef\xfb\xef\xfb\xef\xfb\xef\xfbQ\xc8Q\xc8v9v9v9v9v9v9v9v9v9v9v9v9v9v9v9v9Q\xc8Q\xc8Q\xc8Q\xc8\xdf\x16\xdf\x16\xdf\x16\xdf\x16\xdf\x16\xdf\x16Q\xc8Q\xc8\xef\xfb\xef\xfb\xef\xfb\xef\xfbQ\xc8Q\xc8v9v9v9v9v9v9v9v9v9v9v9v9v9v9Q\xc8Q\xc8\xdf\x16\xdf\x16\xdf\x16\xdf\x16\xd5\xe4\xd5\xe4\xd5\xe4\xd5\xe4Q\xc8Q\xc8\xef\xfb\xef\xfb\xef\xfb\xef\xfb\xef\xfb\xef\xfb\xef\xfb\xef\xfbQ\xc8Q\xc8v9v9v9v9v9v9v9v9v9v9v9v9Q\xc8Q\xc8\xdf\x16\xdf\x16\xdf\x16\xdf\x16\xd5\xe4\xd5\xe4\xd5\xe4\xd5\xe4Q\xc8Q\xc8\xef\xfb\xef\xfb\xef\xfb\xef\xfb\xef\xfb\xef\xfb\xef\xfb\xef\xfbQ\xc8Q\xc8v9v9v9v9v9v9v9v9v9v9Q\xc8Q\xc8\xdf\x16\xdf\x16\xd5\xe4\xd5\xe4\xd5\xe4\xd5\xe4\xd5\xe4\xd5\xe4\xd5\xe4\xd5\xe4Q\xc8Q\xc8\xce\x18\xce\x18\xef\xfb\xef\xfb\xef\xfb\xef\xfbQ\xc8Q\xc8\xef\xfb\xef\xfbQ\xc8Q\xc8v9v9v9v9v9v9v9v9Q\xc8Q\xc8\xdf\x16\xdf\x16\xd5\xe4\xd5\xe4\xd5\xe4\xd5\xe4\xd5\xe4\xd5\xe4\xd5\xe4\xd5\xe4Q\xc8Q\xc8\xce\x18\xce\x18\xef\xfb\xef\xfb\xef\xfb\xef\xfbQ\xc8Q\xc8\xef\xfb\xef\xfbQ\xc8Q\xc8v9v9v9v9v9v9Q\xc8Q\xc8\xd5\xe4\xd5\xe4\xd5\xe4\xd5\xe4\xd5\xe4\xd5\xe4\xd5\xe4\xd5\xe4\xd5\xe4\xd5\xe4\xd5\xe4\xd5\xe4Q\xc8Q\xc8\xce\x18\xce\x18\xef\xfb\xef\xfb\xef\xfb\xef\xfbQ\xc8Q\xc8\xef\xfb\xef\xfbQ\xc8Q\xc8v9v9v9v9v9v9Q\xc8Q\xc8\xd5\xe4\xd5\xe4\xd5\xe4\xd5\xe4\xd5\xe4\xd5\xe4\xd5\xe4\xd5\xe4\xd5\xe4\xd5\xe4\xd5\xe4\xd5\xe4Q\xc8Q\xc8\xce\x18\xce\x18\xef\xfb\xef\xfb\xef\xfb\xef\xfbQ\xc8Q\xc8\xef\xfb\xef\xfbQ\xc8Q\xc8v9v9v9v9v9v9Q\xc8Q\xc8\xd5\xe4\xd5\xe4\xd5\xe4\xd5\xe4\xd5\xe4\xd5\xe4\xd5\xe4\xd5\xe4\xd5\xe4\xd5\xe4\xd5\xe4\xd5\xe4\xd5\xe4\xd5\xe4Q\xc8Q\xc8\xce\x18\xce\x18\xef\xfb\xef\xfb\xef\xfb\xef\xfb\xef\xfb\xef\xfbQ\xc8Q\xc8v9v9v9v9v9v9Q\xc8Q\xc8\xd5\xe4\xd5\xe4\xd5\xe4\xd5\xe4\xd5\xe4\xd5\xe4\xd5\xe4\xd5\xe4\xd5\xe4\xd5\xe4\xd5\xe4\xd5\xe4\xd5\xe4\xd5\xe4Q\xc8Q\xc8\xce\x18\xce\x18\xef\xfb\xef\xfb\xef\xfb\xef\xfb\xef\xfb\xef\xfbQ\xc8Q\xc8v9v9v9v9v9v9Q\xc8Q\xc8Q\xc8Q\xc8Q\xc8Q\xc8Q\xc8Q\xc8Q\xc8Q\xc8\xd5\xe4\xd5\xe4\xd5\xe4\xd5\xe4\xd5\xe4\xd5\xe4\xd5\xe4\xd5\xe4Q\xc8Q\xc8Q\xc8Q\xc8Q\xc8Q\xc8Q\xc8Q\xc8Q\xc8Q\xc8Q\xc8Q\xc8v9v9v9v9Q\xc8Q\xc8Q\xc8Q\xc8Q\xc8Q\xc8Q\xc8Q\xc8Q\xc8Q\xc8\xd5\xe4\xd5\xe4\xd5\xe4\xd5\xe4\xd5\xe4\xd5\xe4\xd5\xe4\xd5\xe4Q\xc8Q\xc8Q\xc8Q\xc8Q\xc8Q\xc8Q\xc8Q\xc8Q\xc8Q\xc8Q\xc8Q\xc8v9v9Q\xc8Q\xc8\xd5\xe4\xd5\xe4\xdf\x16\xdf\x16\xdf\x16\xdf\x16\xdf\x16\xdf\x16\xd5\xe4\xd5\xe4Q\xc8Q\xc8\xd5\xe4\xd5\xe4\xd5\xe4\xd5\xe4Q\xc8Q\xc8\xea\x88\xea\x88\xea\x88\xea\x88\xea\x88\xea\x88\xea\x88\xea\x88\xea\x88\xea\x88\xea\x88\xea\x88Q\xc8Q\xc8Q\xc8Q\xc8\xd5\xe4\xd5\xe4\xdf\x16\xdf\x16\xdf\x16\xdf\x16\xdf\x16\xdf\x16\xd5\xe4\xd5\xe4Q\xc8Q\xc8\xd5\xe4\xd5\xe4\xd5\xe4\xd5\xe4Q\xc8Q\xc8\xea\x88\xea\x88\xea\x88\xea\x88\xea\x88\xea\x88\xea\x88\xea\x88\xea\x88\xea\x88\xea\x88\xea\x88Q\xc8Q\xc8Q\xc8Q\xc8\xdf\x16\xdf\x16\xdf\x16\xdf\x16\xdf\x16\xdf\x16\xdf\x16\xdf\x16Q\xc8Q\xc8\xe4\x02\xe4\x02\xe4\x02\xe4\x02Q\xc8Q\xc8\xea\x88\xea\x88Q\xc8Q\xc8Q\xc8Q\xc8Q\xc8Q\xc8Q\xc8Q\xc8Q\xc8Q\xc8Q\xc8Q\xc8v9v9Q\xc8Q\xc8\xdf\x16\xdf\x16\xdf\x16\xdf\x16\xdf\x16\xdf\x16\xdf\x16\xdf\x16Q\xc8Q\xc8\xe4\x02\xe4\x02\xe4\x02\xe4\x02Q\xc8Q\xc8\xea\x88\xea\x88Q\xc8Q\xc8Q\xc8Q\xc8Q\xc8Q\xc8Q\xc8Q\xc8Q\xc8Q\xc8Q\xc8Q\xc8v9v9Q\xc8Q\xc8\xdf\x16\xdf\x16\xdf\x16\xdf\x16\xd5\xe4\xd5\xe4Q\xc8Q\xc8\xe4\x02\xe4\x02\xe4\x02\xe4\x02\xe4\x02\xe4\x02\xe4\x02\xe4\x02Q\xc8Q\xc8\xea\x88\xea\x88\xea\x88\xea\x88\xea\x88\xea\x88\xea\x88\xea\x88\xea\x88\xea\x88Q\xc8Q\xc8v9v9Q\xc8Q\xc8\xdf\x16\xdf\x16\xdf\x16\xdf\x16\xd5\xe4\xd5\xe4Q\xc8Q\xc8\xe4\x02\xe4\x02\xe4\x02\xe4\x02\xe4\x02\xe4\x02\xe4\x02\xe4\x02Q\xc8Q\xc8\xea\x88\xea\x88\xea\x88\xea\x88\xea\x88\xea\x88\xea\x88\xea\x88\xea\x88\xea\x88Q\xc8Q\xc8v9v9v9v9Q\xc8Q\xc8Q\xc8Q\xc8Q\xc8Q\xc8Q\xc8Q\xc8\xe4\x02\xe4\x02\xe4\x02\xe4\x02\xe4\x02\xe4\x02\xe4\x02\xe4\x02\xe4\x02\xe4\x02Q\xc8Q\xc8Q\xc8Q\xc8Q\xc8Q\xc8Q\xc8Q\xc8Q\xc8Q\xc8v9v9v9v9v9v9Q\xc8Q\xc8Q\xc8Q\xc8Q\xc8Q\xc8Q\xc8Q\xc8\xe4\x02\xe4\x02\xe4\x02\xe4\x02\xe4\x02\xe4\x02\xe4\x02\xe4\x02\xe4\x02\xe4\x02Q\xc8Q\xc8Q\xc8Q\xc8Q\xc8Q\xc8Q\xc8Q\xc8Q\xc8Q\xc8v9v9v9v9v9v9v9v9v9v9v9v9v9v9Q\xc8Q\xc8Q\xc8Q\xc8Q\xc8Q\xc8Q\xc8Q\xc8Q\xc8Q\xc8v9v9v9v9v9v9v9v9v9v9v9v9v9v9v9v9v9v9v9v9v9v9v9v9Q\xc8Q\xc8Q\xc8Q\xc8Q\xc8Q\xc8Q\xc8Q\xc8Q\xc8Q\xc8v9v9v9v9v9v9v9v9v9v9v9v9v9v9')

sprite2_34x24=bytearray(b'v9v9v9v9v9v9v9v9v9v9v9v9Q\xc8Q\xc8Q\xc8Q\xc8Q\xc8Q\xc8Q\xc8Q\xc8Q\xc8Q\xc8Q\xc8Q\xc8v9v9v9v9v9v9v9v9v9v9v9v9v9v9v9v9v9v9v9v9v9v9Q\xc8Q\xc8Q\xc8Q\xc8Q\xc8Q\xc8Q\xc8Q\xc8Q\xc8Q\xc8Q\xc8Q\xc8v9v9v9v9v9v9v9v9v9v9v9v9v9v9v9v9v9v9Q\xc8Q\xc8Q\xc8Q\xc8\xdf\x16\xdf\x16\xdf\x16\xdf\x16\xdf\x16\xdf\x16Q\xc8Q\xc8\xef\xfb\xef\xfb\xef\xfb\xef\xfbQ\xc8Q\xc8v9v9v9v9v9v9v9v9v9v9v9v9v9v9v9v9Q\xc8Q\xc8Q\xc8Q\xc8\xdf\x16\xdf\x16\xdf\x16\xdf\x16\xdf\x16\xdf\x16Q\xc8Q\xc8\xef\xfb\xef\xfb\xef\xfb\xef\xfbQ\xc8Q\xc8v9v9v9v9v9v9v9v9v9v9v9v9v9v9Q\xc8Q\xc8\xdf\x16\xdf\x16\xdf\x16\xdf\x16\xd5\xe4\xd5\xe4\xd5\xe4\xd5\xe4Q\xc8Q\xc8\xef\xfb\xef\xfb\xef\xfb\xef\xfb\xef\xfb\xef\xfb\xef\xfb\xef\xfbQ\xc8Q\xc8v9v9v9v9v9v9v9v9v9v9v9v9Q\xc8Q\xc8\xdf\x16\xdf\x16\xdf\x16\xdf\x16\xd5\xe4\xd5\xe4\xd5\xe4\xd5\xe4Q\xc8Q\xc8\xef\xfb\xef\xfb\xef\xfb\xef\xfb\xef\xfb\xef\xfb\xef\xfb\xef\xfbQ\xc8Q\xc8v9v9v9v9v9v9v9v9v9v9Q\xc8Q\xc8\xdf\x16\xdf\x16\xd5\xe4\xd5\xe4\xd5\xe4\xd5\xe4\xd5\xe4\xd5\xe4\xd5\xe4\xd5\xe4Q\xc8Q\xc8\xce\x18\xce\x18\xef\xfb\xef\xfb\xef\xfb\xef\xfbQ\xc8Q\xc8\xef\xfb\xef\xfbQ\xc8Q\xc8v9v9v9v9v9v9v9v9Q\xc8Q\xc8\xdf\x16\xdf\x16\xd5\xe4\xd5\xe4\xd5\xe4\xd5\xe4\xd5\xe4\xd5\xe4\xd5\xe4\xd5\xe4Q\xc8Q\xc8\xce\x18\xce\x18\xef\xfb\xef\xfb\xef\xfb\xef\xfbQ\xc8Q\xc8\xef\xfb\xef\xfbQ\xc8Q\xc8v9v9v9v9v9v9Q\xc8Q\xc8\xd5\xe4\xd5\xe4\xd5\xe4\xd5\xe4\xd5\xe4\xd5\xe4\xd5\xe4\xd5\xe4\xd5\xe4\xd5\xe4\xd5\xe4\xd5\xe4Q\xc8Q\xc8\xce\x18\xce\x18\xef\xfb\xef\xfb\xef\xfb\xef\xfbQ\xc8Q\xc8\xef\xfb\xef\xfbQ\xc8Q\xc8v9v9v9v9v9v9Q\xc8Q\xc8\xd5\xe4\xd5\xe4\xd5\xe4\xd5\xe4\xd5\xe4\xd5\xe4\xd5\xe4\xd5\xe4\xd5\xe4\xd5\xe4\xd5\xe4\xd5\xe4Q\xc8Q\xc8\xce\x18\xce\x18\xef\xfb\xef\xfb\xef\xfb\xef\xfbQ\xc8Q\xc8\xef\xfb\xef\xfbQ\xc8Q\xc8v9v9v9v9v9v9Q\xc8Q\xc8Q\xc8Q\xc8Q\xc8Q\xc8Q\xc8Q\xc8Q\xc8Q\xc8\xd5\xe4\xd5\xe4\xd5\xe4\xd5\xe4\xd5\xe4\xd5\xe4Q\xc8Q\xc8\xce\x18\xce\x18\xef\xfb\xef\xfb\xef\xfb\xef\xfb\xef\xfb\xef\xfbQ\xc8Q\xc8v9v9v9v9v9v9Q\xc8Q\xc8Q\xc8Q\xc8Q\xc8Q\xc8Q\xc8Q\xc8Q\xc8Q\xc8\xd5\xe4\xd5\xe4\xd5\xe4\xd5\xe4\xd5\xe4\xd5\xe4Q\xc8Q\xc8\xce\x18\xce\x18\xef\xfb\xef\xfb\xef\xfb\xef\xfb\xef\xfb\xef\xfbQ\xc8Q\xc8v9v9v9v9Q\xc8Q\xc8\xdf\x16\xdf\x16\xdf\x16\xdf\x16\xdf\x16\xdf\x16\xdf\x16\xdf\x16\xdf\x16\xdf\x16Q\xc8Q\xc8\xd5\xe4\xd5\xe4\xd5\xe4\xd5\xe4\xd5\xe4\xd5\xe4Q\xc8Q\xc8Q\xc8Q\xc8Q\xc8Q\xc8Q\xc8Q\xc8Q\xc8Q\xc8Q\xc8Q\xc8v9v9Q\xc8Q\xc8\xdf\x16\xdf\x16\xdf\x16\xdf\x16\xdf\x16\xdf\x16\xdf\x16\xdf\x16\xdf\x16\xdf\x16Q\xc8Q\xc8\xd5\xe4\xd5\xe4\xd5\xe4\xd5\xe4\xd5\xe4\xd5\xe4Q\xc8Q\xc8Q\xc8Q\xc8Q\xc8Q\xc8Q\xc8Q\xc8Q\xc8Q\xc8Q\xc8Q\xc8v9v9Q\xc8Q\xc8\xd5\xe4\xd5\xe4\xdf\x16\xdf\x16\xdf\x16\xdf\x16\xdf\x16\xdf\x16\xd5\xe4\xd5\xe4Q\xc8Q\xc8\xd5\xe4\xd5\xe4\xd5\xe4\xd5\xe4Q\xc8Q\xc8\xea\x88\xea\x88\xea\x88\xea\x88\xea\x88\xea\x88\xea\x88\xea\x88\xea\x88\xea\x88\xea\x88\xea\x88Q\xc8Q\xc8Q\xc8Q\xc8\xd5\xe4\xd5\xe4\xdf\x16\xdf\x16\xdf\x16\xdf\x16\xdf\x16\xdf\x16\xd5\xe4\xd5\xe4Q\xc8Q\xc8\xd5\xe4\xd5\xe4\xd5\xe4\xd5\xe4Q\xc8Q\xc8\xea\x88\xea\x88\xea\x88\xea\x88\xea\x88\xea\x88\xea\x88\xea\x88\xea\x88\xea\x88\xea\x88\xea\x88Q\xc8Q\xc8v9v9Q\xc8Q\xc8Q\xc8Q\xc8Q\xc8Q\xc8Q\xc8Q\xc8Q\xc8Q\xc8\xe4\x02\xe4\x02\xe4\x02\xe4\x02Q\xc8Q\xc8\xea\x88\xea\x88Q\xc8Q\xc8Q\xc8Q\xc8Q\xc8Q\xc8Q\xc8Q\xc8Q\xc8Q\xc8Q\xc8Q\xc8v9v9v9v9Q\xc8Q\xc8Q\xc8Q\xc8Q\xc8Q\xc8Q\xc8Q\xc8Q\xc8Q\xc8\xe4\x02\xe4\x02\xe4\x02\xe4\x02Q\xc8Q\xc8\xea\x88\xea\x88Q\xc8Q\xc8Q\xc8Q\xc8Q\xc8Q\xc8Q\xc8Q\xc8Q\xc8Q\xc8Q\xc8Q\xc8v9v9v9v9v9v9Q\xc8Q\xc8\xe4\x02\xe4\x02\xe4\x02\xe4\x02\xe4\x02\xe4\x02\xe4\x02\xe4\x02\xe4\x02\xe4\x02\xe4\x02\xe4\x02Q\xc8Q\xc8\xea\x88\xea\x88\xea\x88\xea\x88\xea\x88\xea\x88\xea\x88\xea\x88\xea\x88\xea\x88Q\xc8Q\xc8v9v9v9v9v9v9Q\xc8Q\xc8\xe4\x02\xe4\x02\xe4\x02\xe4\x02\xe4\x02\xe4\x02\xe4\x02\xe4\x02\xe4\x02\xe4\x02\xe4\x02\xe4\x02Q\xc8Q\xc8\xea\x88\xea\x88\xea\x88\xea\x88\xea\x88\xea\x88\xea\x88\xea\x88\xea\x88\xea\x88Q\xc8Q\xc8v9v9v9v9v9v9v9v9Q\xc8Q\xc8Q\xc8Q\xc8\xe4\x02\xe4\x02\xe4\x02\xe4\x02\xe4\x02\xe4\x02\xe4\x02\xe4\x02\xe4\x02\xe4\x02Q\xc8Q\xc8Q\xc8Q\xc8Q\xc8Q\xc8Q\xc8Q\xc8Q\xc8Q\xc8v9v9v9v9v9v9v9v9v9v9Q\xc8Q\xc8Q\xc8Q\xc8\xe4\x02\xe4\x02\xe4\x02\xe4\x02\xe4\x02\xe4\x02\xe4\x02\xe4\x02\xe4\x02\xe4\x02Q\xc8Q\xc8Q\xc8Q\xc8Q\xc8Q\xc8Q\xc8Q\xc8Q\xc8Q\xc8v9v9v9v9v9v9v9v9v9v9v9v9v9v9Q\xc8Q\xc8Q\xc8Q\xc8Q\xc8Q\xc8Q\xc8Q\xc8Q\xc8Q\xc8v9v9v9v9v9v9v9v9v9v9v9v9v9v9v9v9v9v9v9v9v9v9v9v9Q\xc8Q\xc8Q\xc8Q\xc8Q\xc8Q\xc8Q\xc8Q\xc8Q\xc8Q\xc8v9v9v9v9v9v9v9v9v9v9v9v9v9v9')

sprite3_34x24=bytearray(b'v9v9v9v9v9v9v9v9v9v9v9v9Q\xc8Q\xc8Q\xc8Q\xc8Q\xc8Q\xc8Q\xc8Q\xc8Q\xc8Q\xc8Q\xc8Q\xc8v9v9v9v9v9v9v9v9v9v9v9v9v9v9v9v9v9v9v9v9v9v9Q\xc8Q\xc8Q\xc8Q\xc8Q\xc8Q\xc8Q\xc8Q\xc8Q\xc8Q\xc8Q\xc8Q\xc8v9v9v9v9v9v9v9v9v9v9v9v9v9v9v9v9v9v9Q\xc8Q\xc8Q\xc8Q\xc8\xdf\x16\xdf\x16\xdf\x16\xdf\x16\xdf\x16\xdf\x16Q\xc8Q\xc8\xef\xfb\xef\xfb\xef\xfb\xef\xfbQ\xc8Q\xc8v9v9v9v9v9v9v9v9v9v9v9v9v9v9v9v9Q\xc8Q\xc8Q\xc8Q\xc8\xdf\x16\xdf\x16\xdf\x16\xdf\x16\xdf\x16\xdf\x16Q\xc8Q\xc8\xef\xfb\xef\xfb\xef\xfb\xef\xfbQ\xc8Q\xc8v9v9v9v9v9v9v9v9v9v9v9v9v9v9Q\xc8Q\xc8\xdf\x16\xdf\x16\xdf\x16\xdf\x16\xd5\xe4\xd5\xe4\xd5\xe4\xd5\xe4Q\xc8Q\xc8\xef\xfb\xef\xfb\xef\xfb\xef\xfb\xef\xfb\xef\xfb\xef\xfb\xef\xfbQ\xc8Q\xc8v9v9v9v9v9v9v9v9v9v9v9v9Q\xc8Q\xc8\xdf\x16\xdf\x16\xdf\x16\xdf\x16\xd5\xe4\xd5\xe4\xd5\xe4\xd5\xe4Q\xc8Q\xc8\xef\xfb\xef\xfb\xef\xfb\xef\xfb\xef\xfb\xef\xfb\xef\xfb\xef\xfbQ\xc8Q\xc8v9v9v9v9v9v9v9v9Q\xc8Q\xc8Q\xc8Q\xc8Q\xc8Q\xc8Q\xc8Q\xc8\xd5\xe4\xd5\xe4\xd5\xe4\xd5\xe4\xd5\xe4\xd5\xe4Q\xc8Q\xc8\xce\x18\xce\x18\xef\xfb\xef\xfb\xef\xfb\xef\xfbQ\xc8Q\xc8\xef\xfb\xef\xfbQ\xc8Q\xc8v9v9v9v9v9v9Q\xc8Q\xc8Q\xc8Q\xc8Q\xc8Q\xc8Q\xc8Q\xc8\xd5\xe4\xd5\xe4\xd5\xe4\xd5\xe4\xd5\xe4\xd5\xe4Q\xc8Q\xc8\xce\x18\xce\x18\xef\xfb\xef\xfb\xef\xfb\xef\xfbQ\xc8Q\xc8\xef\xfb\xef\xfbQ\xc8Q\xc8v9v9v9v9Q\xc8Q\xc8\xdf\x16\xdf\x16\xdf\x16\xdf\x16\xdf\x16\xdf\x16\xdf\x16\xdf\x16Q\xc8Q\xc8\xd5\xe4\xd5\xe4\xd5\xe4\xd5\xe4Q\xc8Q\xc8\xce\x18\xce\x18\xef\xfb\xef\xfb\xef\xfb\xef\xfbQ\xc8Q\xc8\xef\xfb\xef\xfbQ\xc8Q\xc8v9v9v9v9Q\xc8Q\xc8\xdf\x16\xdf\x16\xdf\x16\xdf\x16\xdf\x16\xdf\x16\xdf\x16\xdf\x16Q\xc8Q\xc8\xd5\xe4\xd5\xe4\xd5\xe4\xd5\xe4Q\xc8Q\xc8\xce\x18\xce\x18\xef\xfb\xef\xfb\xef\xfb\xef\xfbQ\xc8Q\xc8\xef\xfb\xef\xfbQ\xc8Q\xc8v9v9v9v9Q\xc8Q\xc8\xdf\x16\xdf\x16\xdf\x16\xdf\x16\xdf\x16\xdf\x16\xdf\x16\xdf\x16\xdf\x16\xdf\x16Q\xc8Q\xc8\xd5\xe4\xd5\xe4\xd5\xe4\xd5\xe4Q\xc8Q\xc8\xce\x18\xce\x18\xef\xfb\xef\xfb\xef\xfb\xef\xfb\xef\xfb\xef\xfbQ\xc8Q\xc8v9v9v9v9Q\xc8Q\xc8\xdf\x16\xdf\x16\xdf\x16\xdf\x16\xdf\x16\xdf\x16\xdf\x16\xdf\x16\xdf\x16\xdf\x16Q\xc8Q\xc8\xd5\xe4\xd5\xe4\xd5\xe4\xd5\xe4Q\xc8Q\xc8\xce\x18\xce\x18\xef\xfb\xef\xfb\xef\xfb\xef\xfb\xef\xfb\xef\xfbQ\xc8Q\xc8v9v9v9v9Q\xc8Q\xc8\xd5\xe4\xd5\xe4\xdf\x16\xdf\x16\xdf\x16\xdf\x16\xdf\x16\xdf\x16\xd5\xe4\xd5\xe4Q\xc8Q\xc8\xd5\xe4\xd5\xe4\xd5\xe4\xd5\xe4\xd5\xe4\xd5\xe4Q\xc8Q\xc8Q\xc8Q\xc8Q\xc8Q\xc8Q\xc8Q\xc8Q\xc8Q\xc8Q\xc8Q\xc8v9v9Q\xc8Q\xc8\xd5\xe4\xd5\xe4\xdf\x16\xdf\x16\xdf\x16\xdf\x16\xdf\x16\xdf\x16\xd5\xe4\xd5\xe4Q\xc8Q\xc8\xd5\xe4\xd5\xe4\xd5\xe4\xd5\xe4\xd5\xe4\xd5\xe4Q\xc8Q\xc8Q\xc8Q\xc8Q\xc8Q\xc8Q\xc8Q\xc8Q\xc8Q\xc8Q\xc8Q\xc8v9v9v9v9Q\xc8Q\xc8\xd5\xe4\xd5\xe4\xd5\xe4\xd5\xe4\xd5\xe4\xd5\xe4Q\xc8Q\xc8\xd5\xe4\xd5\xe4\xd5\xe4\xd5\xe4\xd5\xe4\xd5\xe4Q\xc8Q\xc8\xea\x88\xea\x88\xea\x88\xea\x88\xea\x88\xea\x88\xea\x88\xea\x88\xea\x88\xea\x88\xea\x88\xea\x88Q\xc8Q\xc8v9v9Q\xc8Q\xc8\xd5\xe4\xd5\xe4\xd5\xe4\xd5\xe4\xd5\xe4\xd5\xe4Q\xc8Q\xc8\xd5\xe4\xd5\xe4\xd5\xe4\xd5\xe4\xd5\xe4\xd5\xe4Q\xc8Q\xc8\xea\x88\xea\x88\xea\x88\xea\x88\xea\x88\xea\x88\xea\x88\xea\x88\xea\x88\xea\x88\xea\x88\xea\x88Q\xc8Q\xc8v9v9v9v9Q\xc8Q\xc8Q\xc8Q\xc8Q\xc8Q\xc8\xe4\x02\xe4\x02\xe4\x02\xe4\x02\xe4\x02\xe4\x02Q\xc8Q\xc8\xea\x88\xea\x88Q\xc8Q\xc8Q\xc8Q\xc8Q\xc8Q\xc8Q\xc8Q\xc8Q\xc8Q\xc8Q\xc8Q\xc8v9v9v9v9v9v9Q\xc8Q\xc8Q\xc8Q\xc8Q\xc8Q\xc8\xe4\x02\xe4\x02\xe4\x02\xe4\x02\xe4\x02\xe4\x02Q\xc8Q\xc8\xea\x88\xea\x88Q\xc8Q\xc8Q\xc8Q\xc8Q\xc8Q\xc8Q\xc8Q\xc8Q\xc8Q\xc8Q\xc8Q\xc8v9v9v9v9v9v9Q\xc8Q\xc8\xe4\x02\xe4\x02\xe4\x02\xe4\x02\xe4\x02\xe4\x02\xe4\x02\xe4\x02\xe4\x02\xe4\x02\xe4\x02\xe4\x02Q\xc8Q\xc8\xea\x88\xea\x88\xea\x88\xea\x88\xea\x88\xea\x88\xea\x88\xea\x88\xea\x88\xea\x88Q\xc8Q\xc8v9v9v9v9v9v9Q\xc8Q\xc8\xe4\x02\xe4\x02\xe4\x02\xe4\x02\xe4\x02\xe4\x02\xe4\x02\xe4\x02\xe4\x02\xe4\x02\xe4\x02\xe4\x02Q\xc8Q\xc8\xea\x88\xea\x88\xea\x88\xea\x88\xea\x88\xea\x88\xea\x88\xea\x88\xea\x88\xea\x88Q\xc8Q\xc8v9v9v9v9v9v9v9v9Q\xc8Q\xc8Q\xc8Q\xc8\xe4\x02\xe4\x02\xe4\x02\xe4\x02\xe4\x02\xe4\x02\xe4\x02\xe4\x02\xe4\x02\xe4\x02Q\xc8Q\xc8Q\xc8Q\xc8Q\xc8Q\xc8Q\xc8Q\xc8Q\xc8Q\xc8v9v9v9v9v9v9v9v9v9v9Q\xc8Q\xc8Q\xc8Q\xc8\xe4\x02\xe4\x02\xe4\x02\xe4\x02\xe4\x02\xe4\x02\xe4\x02\xe4\x02\xe4\x02\xe4\x02Q\xc8Q\xc8Q\xc8Q\xc8Q\xc8Q\xc8Q\xc8Q\xc8Q\xc8Q\xc8v9v9v9v9v9v9v9v9v9v9v9v9v9v9Q\xc8Q\xc8Q\xc8Q\xc8Q\xc8Q\xc8Q\xc8Q\xc8Q\xc8Q\xc8v9v9v9v9v9v9v9v9v9v9v9v9v9v9v9v9v9v9v9v9v9v9v9v9Q\xc8Q\xc8Q\xc8Q\xc8Q\xc8Q\xc8Q\xc8Q\xc8Q\xc8Q\xc8v9v9v9v9v9v9v9v9v9v9v9v9v9v9')
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
while True:
    
    #game settings
    HOLE_SIZE = 130 # pixels
    SPEED = 3
    counter = 0
    sprite_condition = False
    gameover=False

    #sprite settings
    sprite = 0
    x = 50
    y = 50
    vy = 0.0

    #floor settings
    x_f=0
    Y_F=210

    BACKGROUND_COLOR = PicoGameBoy.color(112,197,206)
    FLOOR_COLOR = PicoGameBoy.color(219,218,150)
    
    button_pressed = False
    prev_button_pressed = False

    def print_pipe(x_p1, y_p1) :
        y = y_p1
        pgb.sprite(4, x_p1 ,y)
        
        
        while y>=-52:
            y = y - 52
            pgb.sprite(3, x_p1 ,y)
        
        y = y_p1 + HOLE_SIZE
        pgb.sprite(5, x_p1, y)
        
        while y<240:
            y = y + 52
            pgb.sprite(3, x_p1 ,y)
            
    def intersect(x1,y1,w1,h1,x2,y2,w2,h2):
        
        if x1+w1 < x2:
            return False
        
        if x2+w2 < x1:
            return False
        
        if y1+w1 < y2:
            return False
        
        if y2+w2 < y1:
            return False 
        
        else :
            return True
            
        

    #pipe 1 initialisation
    y_p1 = randint(-10,48)
    x_p1 = 240

    #pipe 2 initialisation
    y_p2 = randint(-10,48)
    x_p2 = 240 +140

    #part_game loop
    while True:
               
        # update the screen :
           
        #the background
        pgb.fill(BACKGROUND_COLOR)
        
        #the main sprite
        pgb.sprite(sprite, int(x), int(y))
        
        if sprite_condition == True :
            counter = counter + 1
            
            if sprite >= 2 :
                    sprite = 0
                    sprite_condition = False
            
            if counter == 3  :
                sprite = sprite + 1
                counter = 0
                
                    
        #pipe 1
        
        print_pipe(x_p1, y_p1)

        #pipe 2
        print_pipe(x_p2, y_p2)
        
        #floor
        
        for i in range(0,6):        
            pgb.sprite(6,x_f+i*98,Y_F)
            pgb.fill_rect(0,Y_F+14,240,240-Y_F-14,FLOOR_COLOR)

        pgb.show()
       
        vy = vy + 0.20
        y = y + vy
             
        prev_button_pressed = button_pressed
        
        if pgb.button_A() or pgb.button_B():
            
            button_pressed = True
        else:
            
            button_pressed = False
            
        if prev_button_pressed==False and button_pressed==True:
            sprite_condition = True
            vy = -4.4
            
        #update the pipes position
        x_p1 = x_p1 - SPEED
        x_p2 = x_p2 - SPEED
        
        #generate pipe 1
        if x_p1 < -52 :                    
            y_p1 = randint(-20,50)
            x_p1 = 240
        
        #generate pipe 2
        if x_p2 < -52 :
            y_p2 = randint(-20,50)
            x_p2 = 240

            
        #update the floors positions
        x_f = x_f - SPEED
        if x_f<=-98:
            x_f=x_f+98    
     
        #Hit Box verification...
        
        if intersect(x,y,32,20,x_p1+1,y_p1-2,52,240):
            gameover=True
            
        if intersect(x,y,32,22,x_p1+1,y_p1 + HOLE_SIZE+12,52-3,0):
            gameover=True
            
        if intersect(x,y,32,20,x_p2+1,y_p2-4,52  ,240):
            gameover=True
            
        if intersect(x,y,32,22,x_p2+1,y_p2 + HOLE_SIZE+12,52-3,0):
            gameover=True
        
        if y > Y_F :
            gameover=True
            
        if gameover:
            break
        
    #Game over
    
    pgb.fill_rect(120-55,120-30,110,60,PicoGameBoy.color(0,0,0))
    pgb.text("GAME OVER",85,118,PicoGameBoy.color(255,255,255))        
    pgb.show()
    
    time.sleep(1)

    while not pgb.any_button():
        time.sleep(0.1)

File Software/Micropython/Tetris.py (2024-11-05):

# tetris.py by Vincent Mistler for YouMakeTech
# Tetris game for the Raspberry Pi Pico Game Boy

from micropython import const
from PicoGameBoy import PicoGameBoy
import time
from random import randint

BLOCK_SIZE = const(12) # Size of a single tetromino block in pixels
GRID_OFFSET = const(2)
GRID_ROWS  = const(20)
GRID_COLS  = const(10)

pgb = PicoGameBoy()

# image definitions 12x12 pixels
tetris_wall=bytearray(b'\x00\x00\x00\x00\x00\x00\x00\x00\x00\x00\x00\x00\x00\x00\x00\x00\x00\x00\x00\x00\x00\x00\x00\x00\xf7\x9e\xf7\x9e\xf7\x9emX\x00\x00\x00\x00\xf7\x9e\xf7\x9e\xf7\x9emX\x00\x00\x00\x00\xf7\x9e\xf7\x9e\xf7\x9emX\x00\x00\x00\x00\xf7\x9e\xf7\x9e\xf7\x9emX\x00\x00\x00\x00mXmXmX3\x91\x00\x00\x00\x00mXmXmX3\x91\x00\x00\x00\x00mX3\x913\x913\x91\x00\x00\x00\x00mX3\x913\x913\x91\x00\x00\x00\x00mX3\x913\x913\x91\x00\x00\x00\x00mX3\x913\x913\x91\x00\x00\x00\x00\x00\x00\x00\x00\x00\x00\x00\x00\x00\x00\x00\x00\x00\x00\x00\x00\x00\x00\x00\x00\x00\x00\x00\x00mX\x00\x00\x00\x00\xf7\x9e\xf7\x9e\xf7\x9emX\x00\x00\x00\x00\xf7\x9e\xf7\x9e\xf7\x9emX\x00\x00\x00\x00\xf7\x9e\xf7\x9e\xf7\x9emX\x00\x00\x00\x00\xf7\x9e\xf7\x9e\xf7\x9e3\x91\x00\x00\x00\x00mXmXmX3\x91\x00\x00\x00\x00mXmXmX3\x91\x00\x00\x00\x00mX3\x913\x913\x91\x00\x00\x00\x00mX3\x913\x913\x91\x00\x00\x00\x00mX3\x913\x913\x91\x00\x00\x00\x00mX3\x913\x91')
bottom_border=bytearray(b'\xeeP\xf6\x90\xf6\x90\xf6\x90\xf6\x90\xf6\x90\xf6\x90\xf6\x90\xf6\x90\xf6\x90\xf6\x90\xeeP\xf6p\xfe\xb1\xfe\xb1\xfe\xb1\xfe\xb1\xfe\xb1\xfe\xb1\xfe\xb1\xfe\xb1\xfe\xb1\xfe\xb1\xf6p\xdd\x0f\xe5P\xe5P\xe5P\xe5P\xe5P\xe5P\xe5P\xe5P\xe5P\xe5P\xdd\x0fI\x84I\x84I\x84I\x84I\x84I\x84I\x84I\x84I\x84I\x84I\x84I\x84@\xc3H\xc4H\xc4H\xc4H\xc4H\xc4H\xc4H\xc4H\xc4H\xc4H\xc4@\xc3\xd3\r\xdb.\xdb.\xdb.\xdb.\xdb.\xdb.\xdb.\xdb.\xdb.\xdb.\xd3\r\xe4\xef\xed0\xed0\xed0\xed0\xed0\xed0\xed0\xed0\xed0\xed0\xe4\xef\xe5P\xf5p\xf5p\xf5p\xf5p\xf5p\xf5p\xf5p\xf5p\xf5p\xf5p\xe5P\xf6p\xfe\xb1\xfe\xb1\xfe\xb1\xfe\xb1\xfe\xb1\xfe\xb1\xfe\xb1\xfe\xb1\xfe\xb1\xfe\xb1\xf6p\xe5P\xf5p\xf5p\xf5p\xf5p\xf5p\xf5p\xf5p\xf5p\xf5p\xf5p\xe5P\xdc\xef\xe5\x0f\xe5\x0f\xe5\x0f\xe5\x0f\xe5\x0f\xe5\x0f\xe5\x0f\xe5\x0f\xe5\x0f\xe5\x0f\xdc\xefI\x84I\xa4I\xa4I\xa4I\xa4I\xa4I\xa4I\xa4I\xa4I\xa4I\xa4I\x84')
corner=bytearray(b'\x00\x00\x00\x00\x00\x00\x00\x00\x00\x00\x00\x00\x00\x00\x00\x00\x00\x00\x00\x00\x00\x00\x00\x00\x00\x00\xff\xff\xff\xff\xff\xff\xff\xff\xff\xff\xff\xff\xff\xff\xff\xff\xff\xff\xff\xff\x00\x00\x00\x00mX\xff\xff\xff\xff\xff\xff\xff\xff\xff\xff\xff\xff\xff\xff\xff\xffmX\x00\x00\x00\x00mXmX\xff\xff\xff\xff\xff\xff\xff\xff\xff\xff\xff\xffmXmX\x00\x00\x00\x00mXmXmX\xff\xff\xff\xff\xff\xff\xff\xffmXmXmX\x00\x00\x00\x00mXmXmXmX\xff\xff\xff\xffmXmXmXmX\x00\x00\x00\x00mXmXmXmX3\x913\x91mXmXmXmX\x00\x00\x00\x00mXmXmX3\x913\x913\x913\x91mXmXmX\x00\x00\x00\x00mXmX3\x913\x913\x913\x913\x913\x91mXmX\x00\x00\x00\x00mX3\x913\x913\x913\x913\x913\x913\x913\x91mX\x00\x00\x00\x003\x913\x913\x913\x913\x913\x913\x913\x913\x913\x91\x00\x00\x00\x00\x00\x00\x00\x00\x00\x00\x00\x00\x00\x00\x00\x00\x00\x00\x00\x00\x00\x00\x00\x00\x00\x00')
left_border=bytearray(b'\x00\x00\xe3\x0e\xe3\x0e\xedP\xe3\x0e\xe3\x0e\xe3\x0e\x00\x00\x00\x00\xedP\xedP\xedP\x00\x00\xedP\xedP\xfe\xd1\xedP\xedP\xe3\x0e\x00\x00\x00\x00\xedP\xfe\xd1\xfe\xd1\x00\x00\xedP\xedP\xfe\xd1\xedP\xedP\xe3\x0e\x00\x00\x00\x00\xedP\xfe\xd1\xfe\xd1\x00\x00\xedP\xedP\xfe\xd1\xedP\xedP\xe3\x0e\x00\x00\x00\x00\xedP\xfe\xd1\xfe\xd1\x00\x00\xe3\x0e\xe3\x0e\xedP\xe3\x0e\xe3\x0e\x00\x00\x00\x00\x00\x00\xedP\xfe\xd1\xfe\xd1\x00\x00\xe3\x0e\xe3\x0e\xedP\xe3\x0e\xe3\x0e\x00\x00\x00\x00\x00\x00\xedP\xfe\xd1\xfe\xd1\x00\x00\xfe\xd1\xfe\xd1\xfe\xd1\xfe\xd1\xfe\xd1\xedP\x00\x00\x00\x00\xedP\xfe\xd1\xfe\xd1\x00\x00\xedP\xedP\xfe\xd1\xedP\xedP\xe3\x0e\x00\x00\x00\x00\xedP\xfe\xd1\xfe\xd1\x00\x00\xedP\xedP\xfe\xd1\xedP\xedP\xe3\x0e\x00\x00\x00\x00\xedP\xfe\xd1\xfe\xd1\x00\x00\xe3\x0e\xe3\x0e\xedP\xe3\x0e\xe3\x0e\x00\x00\x00\x00\x00\x00\xedP\xfe\xd1\xfe\xd1\x00\x00\xfe\xd1\xfe\xd1\xfe\xd1\xfe\xd1\xfe\xd1\xedP\x00\x00\x00\x00\xedP\xfe\xd1\xfe\xd1\x00\x00\xfe\xd1\xfe\xd1\xfe\xd1\xfe\xd1\xfe\xd1\xedP\x00\x00\x00\x00\xedP\xfe\xd1\xfe\xd1')
right_border=bytearray(b'\xedP\xedP\xedP\x00\x00\x00\x00\xe3\x0e\xe3\x0e\xe3\x0e\xedP\xe3\x0e\xe3\x0e\x00\x00\xfe\xd1\xfe\xd1\xedP\x00\x00\x00\x00\xe3\x0e\xedP\xedP\xfe\xd1\xedP\xedP\x00\x00\xfe\xd1\xfe\xd1\xedP\x00\x00\x00\x00\xe3\x0e\xedP\xedP\xfe\xd1\xedP\xedP\x00\x00\xfe\xd1\xfe\xd1\xedP\x00\x00\x00\x00\xe3\x0e\xedP\xedP\xfe\xd1\xedP\xedP\x00\x00\xfe\xd1\xfe\xd1\xedP\x00\x00\x00\x00\x00\x00\xe3\x0e\xe3\x0e\xedP\xe3\x0e\xe3\x0e\x00\x00\xfe\xd1\xfe\xd1\xedP\x00\x00\x00\x00\x00\x00\xe3\x0e\xe3\x0e\xedP\xe3\x0e\xe3\x0e\x00\x00\xfe\xd1\xfe\xd1\xedP\x00\x00\x00\x00\xedP\xfe\xd1\xfe\xd1\xfe\xd1\xfe\xd1\xfe\xd1\x00\x00\xfe\xd1\xfe\xd1\xedP\x00\x00\x00\x00\xe3\x0e\xedP\xedP\xfe\xd1\xedP\xedP\x00\x00\xfe\xd1\xfe\xd1\xedP\x00\x00\x00\x00\xe3\x0e\xedP\xedP\xfe\xd1\xedP\xedP\x00\x00\xfe\xd1\xfe\xd1\xedP\x00\x00\x00\x00\x00\x00\xe3\x0e\xe3\x0e\xedP\xe3\x0e\xe3\x0e\x00\x00\xfe\xd1\xfe\xd1\xedP\x00\x00\x00\x00\xedP\xfe\xd1\xfe\xd1\xfe\xd1\xfe\xd1\xfe\xd1\x00\x00\xfe\xd1\xfe\xd1\xedP\x00\x00\x00\x00\xedP\xfe\xd1\xfe\xd1\xfe\xd1\xfe\xd1\xfe\xd1\x00\x00')
top_border=bytearray(b'\x00\x00\x00\x00\x00\x00\x00\x00\x00\x00\x00\x00\x00\x00\x00\x00\x00\x00\x00\x00\x00\x00\x00\x00\xedP\xedP\xedP\xedP\xedP\xedP\xedP\xedP\xedP\xedP\xedP\xedP\xedP\xedP\xedP\xedP\xedP\xedP\xedP\xedP\xedP\xedP\xedP\xedP\xfe\xd1\xfe\xd1\xfe\xd1\xfe\xd1\xfe\xd1\xfe\xd1\xfe\xd1\xfe\xd1\xfe\xd1\xfe\xd1\xfe\xd1\xfe\xd1\xedP\xedP\xedP\xedP\xedP\xedP\xedP\xedP\xedP\xedP\xedP\xedP\xedP\xedP\xedP\xedP\xedP\xedP\xedP\xedP\xedP\xedP\xedP\xedP\xe3\x0e\xe3\x0e\xe3\x0e\xe3\x0e\xe3\x0e\xe3\x0e\xe3\x0e\xe3\x0e\xe3\x0e\xe3\x0e\xe3\x0e\xe3\x0e\x00\x00\x00\x00\x00\x00\x00\x00\x00\x00\x00\x00\x00\x00\x00\x00\x00\x00\x00\x00\x00\x00\x00\x00\x00\x00\x00\x00\x00\x00\x00\x00\x00\x00\x00\x00\x00\x00\x00\x00\x00\x00\x00\x00\x00\x00\x00\x00\xedP\xedP\xedP\xedP\xedP\xedP\xedP\xedP\xedP\xedP\xedP\xedP\xfe\xd1\xfe\xd1\xfe\xd1\xfe\xd1\xfe\xd1\xfe\xd1\xfe\xd1\xfe\xd1\xfe\xd1\xfe\xd1\xfe\xd1\xfe\xd1\xfe\xd1\xfe\xd1\xfe\xd1\xfe\xd1\xfe\xd1\xfe\xd1\xfe\xd1\xfe\xd1\xfe\xd1\xfe\xd1\xfe\xd1\xfe\xd1')

pgb.add_sprite(tetris_wall,12,12) #0
pgb.add_sprite(bottom_border,12,12) #1
pgb.add_sprite(corner,12,12) #2
pgb.add_sprite(left_border,12,12) #3
pgb.add_sprite(right_border,12,12) #4
pgb.add_sprite(top_border,12,12) #5


field = [[-1 for col in range(GRID_COLS)] for row in range(GRID_ROWS)]

# shape of the 7 tetrominos
# [0][1]
# [2][3]
# [4][5]
# [6][7]
# e.g. [3,4,5,7] is:
#    [ ]
# [ ][ ]
#    [ ]
tetrominos = [[1,3,5,7],
              [2,4,5,7],
              [3,5,4,6],
              [3,5,4,7],
              [2,3,5,7],
              [3,5,7,6],
              [2,3,4,5]]
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

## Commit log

2024-09-11 Added Kicad files and updated README.md
    First post of Kicad files for prototype
    Update README.md to give detailed project description
    [1.3 TFT IPS.stp, 3214G.stp, 3314G1.stp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]
2024-09-11 Update Gerbers
    Update Gerber files and BOM
    [RLab Keyboard-CuBottom.gbr, RLab Keyboard-CuTop.gbr, RLab Keyboard-EdgeCuts.gbr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]
2024-09-11 Added CircuitPython and Micropython files
2024-09-27 Initial submit of version 1.2
    Update to layout of Kicad files for new user interface
    Added circuit Python test firmware
    [9032.STEP, Athena_Base.stl, Display mount.stl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]
2024-09-28 Generate 3D printable stencil files
2024-10-02 Remove locks on Kicad files
    Remove lock on rLab Keyboard Kicad .sch and .pcb
2024-11-01 Latest rLab Keyboard layout
    Added connectors for joining boards
    Swap display and speaker.
    New control layout
    [Athena_Base.stl, Display mount.stl, RLab Keyboard.kicad_pcb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]
2024-11-05 Add games to Micropython directory
    [RLab Keyboard.kicad_pcb]
2024-11-05 Fix DRC issues in latest KiCAD
    [RLab Keyboard.kicad_pcb]
2024-11-07 Files updated for JLCPCB Assembly
    Added DNP for through hole components. can be viewed as option in 3D viewer.
    Production files in JLCPCB folder
    [RLab Keyboard-CuBottom.gbr, RLab Keyboard-CuTop.gbr, RLab Keyboard-EdgeCuts.gbr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]
2024-11-29 Update README.md
    Update 3D image
    [Display mount.stl]
